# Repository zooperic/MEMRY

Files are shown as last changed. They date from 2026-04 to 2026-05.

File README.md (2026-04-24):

# MEMRY — Roadmap

## Milestone 0 — Decisions & Research ✅
*Completed April 2025*
- Product concept locked (WiFi Live, Polaroid form factor)
- Hardware stack decided (XIAO ESP32C3 + Waveshare 4.2" + 300mAh LiPo)
- India BOM researched with prices in INR
- Architecture designed
- NFC/Snap scoped out for POC (iOS complexity + deadline)

---

## Milestone 1 — Hardware Design ✅
*Completed April 2025*
- [x] Finalise shell dimensions (95×115×11mm)
- [x] Two-piece design: front body + plain back panel (no text, no emboss)
- [x] USB-C notch on right edge
- [x] M2 screw bosses (4 corners, BIN=6mm inset) — secure on impact
- [x] Rim ledge (RIM_W=2.5mm, RIM_H=1.5mm) with gasket groove
- [x] Magnet pockets: blind design spanning both pieces
      — Back panel: 20mm through-hole (1.5mm deep)
      — Front body rim face: 20mm blind recess (2.0mm deep)
      — Combined: 3.5mm total pocket, magnet 3.0mm, 0.5mm PLA floor
      — Ghost rings (raised 0.4mm) mark position on fridge face
- [x] STL files exported and validated (single body, watertight, correct dims)
      — memry_front_body_v4.stl (95×115×11mm)
      — memry_back_panel_v4.stl (87×107×1.9mm, fits inside rim)
- [ ] Submit STLs to local Pune 3D print service (print 4× each)

---

## Milestone 2 — Order Everything
*Target: April 22, 2025 (order) → May 1 (receive)*

### Electronics (Robu.in)
- [ ] 4× Waveshare 4.2" B&W e-ink display (400×300px, SPI)
- [ ] 4× Seeed XIAO ESP32C3
- [ ] 4× 3.7V 300mAh slim LiPo (JST-PH 2.0mm, ~2.5mm thick)
- [ ] Dupont jumper wires F-F 10cm (pack of 40)
- [ ] 1× breadboard (for firmware POC before assembly)

### Hardware (Amazon.in)
- [ ] N52 neodymium disc magnets 20mm×3mm — pack of 20
- [ ] M2×6mm self-tapping screws — pack of 20
- [ ] PCB conformal coating spray (~₹300)

### Consumables (local hardware store)
- [ ] Clear silicone sealant — Fevikwik Silicone or equivalent (~₹80)
- [ ] 2-part epoxy — for locking magnets (~₹60)

### 3D Print (local Pune service)
- [ ] memry_front_body_v4.stl — print 4× (white PLA, 0.15mm, face-down)
- [ ] memry_back_panel_v4.stl — print 4× (white PLA, 0.15mm, outside-face-down)

---

## Milestone 3 — Firmware POC
*Target: when hardware arrives (~May 1)*
*Status: PARKED — display ordered (Waveshare 3.6" Spectra 6), waiting on delivery*

### What's done (pre-hardware)
- [x] Full firmware scaffold: WiFi connect, ETag fetch, deep sleep cycle
- [x] WiFi provisioning portal (captive portal hotspot, no hardcoded creds)
- [x] Battery ADC monitoring spec'd, `bmp_render.h` written (needs color swap)
- [x] Mock server written (Node.js, zero deps)

### Do on hardware arrival
- [ ] Confirm driver chip from PCB sticker → write `color_render.h` (4bpp 6-color)
- [ ] Update display init in `memry.ino` to Spectra 6 driver
- [ ] Wire + breadboard test, run Waveshare stock demo first
- [ ] Flash MEMRY firmware, confirm color image renders
- [ ] End-to-end: upload color photo → appears on display
- [ ] Measure actual current draw in each state

### Shell update (Tinkercad, ~10 min)
- [ ] Resize window: 85x85mm → 85x58mm (Spectra 6 active area 84.6x56.4mm)
- [ ] Bottom strip grows 23mm → ~31mm (more Polaroid-authentic)
- [ ] Re-export STLs, resubmit to Pune printer

---

## Milestone 4 — Web App
*Target: April–May 2025 (building now)*
*Status: IN PROGRESS — starting while hardware ships*

### Stack
- Next.js 14 (App Router) · TypeScript · Tailwind · shadcn/ui
- Supabase (Auth + Postgres + Storage)
- Sharp.js image pipeline (server-side) · Vercel hosting

### Core features
- [ ] Supabase project setup (auth, DB schema, storage bucket)
- [ ] Next.js scaffold with Supabase auth (email/password)
- [ ] Upload flow: drag/drop → 6-color quantise → store BMP
- [ ] Device API: GET /api/device/{id}/current-image (ETag + X-Sleep-Hours + X-Battery-Mv)
- [ ] Dashboard: device cards, current photo, battery level badge, last-seen
- [ ] Storage usage: total bucket size + per-device breakdown
- [ ] Photo manager: set active, delete per-photo, clear all for device
- [ ] Device pairing: enter ID → name it → done
- [ ] Contributor invite by email (owner vs contributor roles)
- [ ] Deploy to Vercel

### Image pipeline (Spectra 6 color)
- [ ] Sharp.js resize to 600x400 (cover, centred)
- [ ] Quantise to 6-color palette: Black/White/Green/Blue/Red/Yellow
- [ ] Pack as 4bpp (2 pixels per byte) for device
- [ ] Store JPEG preview separately for dashboard thumbnails

### Polish
- [ ] Mobile-first (primary users on phone)
- [ ] Polaroid upload preview (simulated 6-color render before sending)
- [ ] Error states: device offline, image too large, upload failure
- [ ] Warm cream/ink aesthetic matching WIKI.html design language

---

## Milestone 5 — Integration + Assembly
*Target: June 2–15, 2025*
- [ ] Point all 4 firmware units at live server
- [ ] End-to-end test: web upload → fridge refresh
- [ ] Test rotation / auto-cycle
- [ ] Test with real photos (dithering quality check)
- [ ] Assemble all 4 shells (follow splash-protection sequence below)
- [ ] Charge all units via USB-C
- [ ] Confirm all 4 units connect to WiFi and poll correctly

### Assembly sequence (per unit)
1. Breadboard test first — confirm display + XIAO + LiPo work
2. Conformal coat — spray XIAO + all solder joints, cure 24h
3. Seat display — place face-down in display bay, route FPC ribbon
4. Seal display edge — thin silicone bead around window perimeter (inside)
5. Seat XIAO + LiPo — component bay, connect FPC jumpers + JST battery
6. Fill gasket groove — clear silicone sealant into rim groove
7. Drop back panel — self-locates inside rim ledge, press evenly
8. Drive 4× M2×6mm screws — corners, firm but don't overtighten
9. Insert magnets — drop N52 into ghost-ring holes from outside
10. Epoxy magnets — fill with 2-part epoxy, cure 30min

---

## Milestone 6 — Polish
*Target: June 16 – July 6, 2025*
- [ ] UI polish — mobile-first web app
- [ ] Polaroid preview on upload (simulated e-ink look)
- [ ] Error handling (device offline, WiFi failure, image too large)
- [ ] Domain: memry.app (or similar)
- [ ] Write setup guide for Jo (one-page PDF gift insert)
- [ ] Label each unit with small ID sticker inside back panel during assembly

---

## Milestone 7 — Gift Ready 🎁
*Target: July 11, 2025 (one week before July 18)*
- [ ] All 4 units assembled, charged, tested
- [ ] Server live and stable
- [ ] Jo's account created, devices paired
- [ ] Friends invited as contributors
- [ ] First photo pre-loaded on each device
- [ ] Gift packaged

---

## v2 Scope (Post-Birthday)

### Near term (Aug–Oct 2025)
- NFC Snap variant — revisit with proper iOS CoreNFC testing
- Flutter app — single interface for both Snap + Live
- Push updates (WebSocket) — instant refresh when photo is published
- Image filters on upload (grayscale styles, contrast, vintage)
- Caption rendering on bottom Polaroid strip

### Medium term (2026)
- Custom PCB — replace XIAO devkit, reduce to 8mm shell
- Injection moulded ABS shell — scale economics
- Direct display factory sourcing (50+ unit MOQ)
- Public launch — anyone can create an account and buy a MEMRY
- Subscription model — free tier (1 device, 5 photos) + paid (unlimited)

### Long term / ideas
- Physical MEMRY store — gift-ready packaged units
- Multi-frame — 2×2 grid of MEMRY units that show one big photo
- Color display — when 6-color NFC panels become more power efficient
- MEMRY for businesses — office walls, conference rooms

---

*Roadmap v1.2 · April 2025 · 87 days to July 11*

---

## LLM / AI Software Roadmap

### v2 — Natural Language Interface
- [ ] LLM command bar: "Show something cheerful on Jo's fridge" → picks + publishes
- [ ] Google Photos OAuth integration
- [ ] Natural language scheduling: "Show beach photos this week"

### v2 — Smart Curation
- [ ] Vision model scores photos for warmth, faces, composition
- [ ] Auto-suggest best photo for fridge
- [ ] Smart album: LLM picks best from a set based on vibe

### v3 — Automation
- [ ] "Every Monday morning, pick a random memory from the past year"
- [ ] Event awareness: birthdays, anniversaries → auto-queue relevant photos
- [ ] Multi-device: "Update all MEMRYs with something warm for the holidays"

---

## Smart Home / Matter Integration (v3+)

### Why Matter
Matter is the open smart home standard backed by Google, Apple, Amazon and Samsung.
ESP32C3 — the exact chip used in MEMRY — is one of Matter's reference MCUs and has
an official Matter SDK. No hardware changes needed.

### What it unlocks
- MEMRY appears in Google Home / Apple Home / Alexa as a native device
- Voice: "Hey Google, cycle the kitchen frame"
- Routines: "Every morning at 8am, show a new photo"
- Local network control — no cloud middleman

### Standards evaluated
| Standard | Verdict |
|---|---|
| **Matter over WiFi** | ✅ Best long-term bet — one standard, all ecosystems, ESP32C3 native |
| **Home Assistant (MQTT/ESPHome)** | ✅ Good for dev/power users, requires self-hosted HA |
| **Google Assistant SDK direct** | ⚠ Deprecated in favour of Matter |
| **Apple HomeKit (esp-homekit-sdk)** | ⚠ Works on ESP32 but MFi cert is a headache for DIY |

### Why it's v3 scope
Matter adds significant firmware complexity — commissioning flow, Thread/WiFi
selection, device descriptors. The POC deadline (July 2025) doesn't allow for it.
The hardware foundation is already correct — it's purely a firmware + web app change.

### Milestone placeholder
- [ ] v3 — Matter commissioning on XIAO ESP32C3
- [ ] v3 — Google Home device type: "Display" or custom "Photo Frame"
- [ ] v3 — Routine support: voice-triggered photo cycle
- [ ] v3 — Home Assistant ESPHome alternative for maker/dev users

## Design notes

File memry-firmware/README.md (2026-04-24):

# MEMRY Firmware — Spectra 6 Color

Hardware confirmed: Waveshare 3.6" e-Paper HAT+ (E), SKU 32650, Spectra 6, 600×400.

---

## File structure

```
firmware_color/
├── memry/
│   ├── memry.ino           ← main sketch (open this in Arduino IDE)
│   ├── config.h            ← per-device settings, edit before flashing
│   ├── epd3in6e_driver.h   ← Spectra 6 SPI driver (no GxEPD2 needed)
│   └── wifi_provision.h    ← captive portal WiFi setup
└── mock-server.js          ← local test server (Node.js, no deps)
```

---

## Arduino IDE setup

### 1. Board package
Preferences → Additional boards URLs:
```
https://files.seeedstudio.com/arduino/package_seeeduino_boards_index.json
```
Install: **Seeed Studio XIAO Series** from Boards Manager.

### 2. Select board
`Tools → Board → Seeed XIAO ESP32C3`

### 3. Libraries (Library Manager)
- `ArduinoJson` by Benoit Blanchon (v6.x)
- No GxEPD2 needed — driver is included in `epd3in6e_driver.h`

---

## Wiring (breadboard test)

Use the **9-pin breakout connector** on the right side of the HAT+ PCB.
Do NOT use the 40-pin Pi header.

```
HAT+ breakout    XIAO ESP32C3
─────────────────────────────────────
GND           →  GND
VCC           →  3.3V
DIN (MOSI)    →  D10  (GPIO3)
CLK (SCK)     →  D8   (GPIO2)
CS            →  D7   (GPIO20)
DC            →  D3   (GPIO21)
RST           →  D0   (GPIO9)
BUSY          ←  D1   (GPIO10)
PWR           →  3.3V  ⚠️ REQUIRED — ties to same 3.3V rail
```

⚠️  **PWR pin is critical.** Without 3.3V on PWR the display will not power on.
    Tie it to the same 3.3V rail as VCC on your breadboard.

⚠️  **Interface switch** on HAT+ PCB must be at position **0** (4-line SPI).
    It ships at 0 — leave it alone.

---

## First flash (step by step)

### 1. Edit config.h
```cpp
#define DEVICE_ID  "memry-001"         // unique per unit
#define SERVER_URL "http://192.168.x.x:3001"  // your laptop LAN IP
```

### 2. Start mock server
```bash
node mock-server.js
```
Prints your LAN IP — paste that into `SERVER_URL`.

### 3. Wire display per table above

### 4. Flash
Open `memry/memry.ino` → Upload.

### 5. Serial Monitor (115200 baud)
You should see:
```
── MEMRY wake #1  device=memry-001 ──
EPD init done
WiFi: connecting to 'YourNetwork' (attempt 1)
WiFi connected: 192.168.1.xx
Battery: 3920mV
Fetching http://192.168.1.42:3001/api/device/memry-001/current-image
HTTP 200
Content-Length: 120000
EPD rendering rotated 120000 bytes (400×600)...
EPD refreshing rotated (this takes ~19s)...
EPD rotated render done in 22438ms
Sleeping 4h...
```

Display will show the 6-color test pattern after ~22 seconds of refreshing.

---

## Orientation

The display's native pixel layout is **landscape** (600 wide × 400 tall).
The shell mounts it **portrait** (400 wide × 600 tall).

The firmware calls `epdRenderRotated()` which rotates the image 90° clockwise
in RAM before sending. This is the default.

If you want landscape orientation, change `memry.ino`:
```cpp
// Change this:
epdRenderRotated(imgBuf, imgLen);
// To this:
epdRender(imgBuf, imgLen);
```

And update the server to produce images at 600×400 (landscape) instead of
rotating them to 400×600 portrait.

---

## Image format

The server sends raw 4bpp packed binary:
- 2 pixels per byte
- High nibble = left pixel, low nibble = right pixel
- Color indices: Black=0, White=1, Green=2, Blue=3, Red=4, Yellow=5
- Total size: 600 × 400 / 2 = **120,000 bytes** exactly

The mock server generates a 6-color test pattern automatically on first run.

To serve your own image:
```bash
# Convert any photo using ImageMagick + custom palette
# (The web app will do this automatically — for manual testing:)
convert your-photo.jpg \
  -resize 600x400^ -gravity center -extent 600x400 \
  -dither FloydSteinberg \
  -remap spectra6-palette.png \
  your-photo-quantised.png
# Then convert to raw 4bpp using the included convert.js script
```

---

## Mock server quick reference

```bash
# Regenerate test pattern
curl http://localhost:3001/test-pattern

# Force device to re-render on next wake
curl http://localhost:3001/reset-etag

# See server state + recent device requests
curl http://localhost:3001/status
```

---

## Per-unit checklist

| Unit | DEVICE_ID | WiFi via portal | Flashed | Display tested |
|---|---|---|---|---|
| 1 | memry-001 | [ ] | [ ] | [ ] |
| 2 | memry-002 | [ ] | [ ] | [ ] |
| 3 | memry-003 | [ ] | [ ] | [ ] |
| 4 | memry-004 | [ ] | [ ] | [ ] |

---

## Troubleshooting

| Symptom | Cause | Fix |
|---|---|-----|
| Display stays white/blank | PWR pin not connected | Wire PWR → 3.3V |
| BUSY timeout in Serial | Wrong wiring | Re-check all 8 pins |
| Image garbled/wrong colors | Wrong resolution sent | Confirm 120,000 bytes |
| WiFi never connects | First boot | Connect to "MEMRY-Setup" hotspot |
| Crash / malloc failed | 120KB not available | Unlikely on XIAO C3 (400KB) — check other allocations |
| Refresh takes >60s | BUSY stuck HIGH | Check BUSY wiring and RST pulse |

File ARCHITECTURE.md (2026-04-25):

# MEMRY — Architecture

## System Overview

```
[Person] ──upload──▶ [Web App] ──store──▶ [Supabase]
                         │                    │
                   [Image Pipeline]            │
                   Sharp.js                    │
                   → color quantise (Spectra 6)│
                   → Floyd-Steinberg (B&W)     │
                   → BMP output                │
                         │                    │
                   [Storage bucket] ◀──────────┘
                         │
              GET /api/device/{id}/current-image
                         │
                  [MEMRY Device]
          XIAO ESP32C3 wakes from deep sleep
          → WiFi connect → poll server
          → receive BMP → render to e-ink
          → hibernate display → deep sleep
```

---

## Hardware Layer

### Device Stack (per unit)
```
Front wall (1.0mm PLA)
Display glass (1.2mm) + PCB driver (1.5mm)
FPC ribbon gap (0.5mm)
XIAO ESP32C3 (3.5mm) beside LiPo (2.5mm)
Rim ledge + back panel (1.5mm PLA)
─────────────────────────────────────────
~11mm total
```

### Shell (v4 — two-piece)
- **Front body:** 95×115×11mm · display window · component bay · rim ledge · gasket groove · M2 boss pillars
- **Back panel:** 87×107×1.9mm · ghost rings · magnet through-holes · M2 countersunk holes
- **Closure:** 4× M2×6mm self-tapping screws through panel → into boss pillars
- **Magnets:** N52 20mm×3mm disc · blind pocket split across both pieces · epoxied post-assembly
- **Splash resistance:** silicone sealant in gasket groove + conformal coat on electronics

### Display Decision
- **Confirmed:** Waveshare 3.6" E-Paper HAT+ (E) — SKU 32650
  - Panel: Spectra 6 (E6) — 6-pigment ACeP technology
  - Resolution: 600×400px (landscape) → 400×600px (portrait mounted in shell)
  - Active area: 84.6×56.4mm
  - Driver chip: UC8253 (confirmed from PCB + datasheet)
  - Interface: 4-line SPI (switch set to position 0)
  - Refresh time: ~19 seconds full update
  - Color encoding: 4bpp packed, 2px/byte (6 colors: B/W/G/B/R/Y)
  - Power requirements: PWR pin MUST tie to 3.3V (critical!)
  - Portrait mounting: setRotation(1) in firmware for landscape shell
  - Portrait mounted in landscape shell via setRotation(1)
- **Dropped:** Waveshare 4.2" B&W (original plan — superseded by color)

### Power Budget
```
State               Current      Duration      Energy/day
─────────────────────────────────────────────────────────
Deep sleep          44µA         ~23h 59m      ~1.06 mWh
WiFi connect        ~80mA avg    ~8 seconds    ~0.18 mWh
Image fetch         ~60mA        ~3 seconds    ~0.05 mWh
E-ink refresh       ~26mA        ~4 seconds    ~0.03 mWh
E-ink sleep         ~0µA         always after  0 mWh
─────────────────────────────────────────────────────────
Total/day                                      ~1.32 mWh

Battery: 300mAh × 3.7V × 0.85 = 944 mWh usable
Life: 944 / 1.32 ≈ 715 days theoretical → realistic 3–5 months
```

### Wiring
```
Waveshare e-ink     →   XIAO ESP32C3
────────────────────────────────────
VCC              →   3.3V
GND              →   GND
DIN (MOSI)       →   D10 (GPIO3)
CLK (SCK)        →   D8  (GPIO2)
CS               →   D7  (GPIO20)
DC               →   D3  (GPIO21)
RST              →   D0  (GPIO9)
BUSY             ←   D1  (GPIO10)

LiPo 300mAh      →   XIAO BAT+ / BAT-  (JST-PH 2.0mm)
USB-C            →   XIAO USB-C (charge + flash)
```

---

## Firmware Layer

### Lifecycle
```
Boot / wake from deep sleep
  │
  ├─ Connect WiFi (stored creds) — timeout 20s, retry 3×
  ├─ GET /api/device/{DEVICE_ID}/current-image
  │    → check ETag (stored in RTC memory)
  │    → if unchanged: skip render, sleep immediately
├─ Render BMP to e-ink (custom epd3in6e_driver.h) — ~19s full refresh
  ├─ Display hibernate (0µA)
  └─ Deep sleep SLEEP_INTERVAL (default 4h, from X-Sleep-Hours header)
```

### Key Config
```cpp
const char* WIFI_SSID  = "Jo_WiFi";
const char* WIFI_PASS  = "password";
const char* DEVICE_ID  = "memry-001";
const char* SERVER     = "https://api.memry.app";
uint64_t    SLEEP_US   = 4ULL * 3600 * 1000000;
```

### Libraries
```
GxEPD2       (NOT USED NOW) E-ink driver (supports Waveshare 4" Spectra 6 + 4.2" B&W) 
HTTPClient    HTTP requests
ArduinoJson   Parse response headers
Preferences   Store WiFi creds + device ID in flash
WiFi          Network connectivity (ESP32 built-in)
WebServer     Provisioning portal (ESP32 built-in)
DNSServer     Captive portal for WiFi setup (ESP32 built-in)

Custom drivers (no external deps):
epd3in6e_driver.h    SPI driver for Waveshare 3.6" Spectra 6
wifi_provision.h     Captive portal WiFi provisioning
bmp_render.h         Direct framebuffer rendering (no font libs)
```

---

## Software Layer

### Web App Stack
```
Next.js 14 (App Router)
  ├── /app
  │     ├── page.tsx              ← Dashboard
  │     ├── /device/[id]          ← Photo manager
  │     └── /upload               ← Upload + preview
  ├── /api
  │     ├── /device/[id]/image    ← Device-facing: serve BMP
  │     ├── /devices              ← CRUD
  │     └── /photos               ← Upload, publish, delete
  └── /lib
        ├── supabase.ts
        ├── imageProcess.ts       ← Sharp.js pipeline
        └── dither.ts             ← Color quantise + Floyd-Steinberg

Supabase: Auth · Postgres · Storage (private buckets)
Hosting: Vercel (free tier)
```

### Image Processing Pipeline
```
Upload (JPEG/PNG/HEIC)
  │
  ├─ Resize to 600×400 (cover, centre crop) — Sharp.js
  │
  ├─ Quantise to 6-color Spectra 6 palette
  │    Black=0x0 · White=0x1 · Green=0x2 · Blue=0x3 · Red=0x4 · Yellow=0x5
  │    Each pixel = 4 bits · 2 pixels packed per byte
  │
  ├─ Output: raw 4bpp packed buffer (~120KB) → device format
  │   + JPEG preview at 600×400 for dashboard thumbnails
  │
  └─ Store in Supabase Storage
       /processed/{device_id}/{photo_id}.bin   ← device image
       /previews/{device_id}/{photo_id}.jpg    ← dashboard thumbnail
```

### Database Schema
```sql
CREATE TABLE devices (
  id            TEXT PRIMARY KEY,        -- 'memry-001'
  name          TEXT,                    -- 'Jo's Kitchen'
  owner_id      UUID REFERENCES auth.users,
  sleep_hours   INT DEFAULT 4,
  display_type  TEXT DEFAULT 'color',    -- 'color' | 'bw'
  created_at    TIMESTAMPTZ DEFAULT NOW()
);

CREATE TABLE photos (
  id              UUID PRIMARY KEY DEFAULT gen_random_uuid(),
  device_id       TEXT REFERENCES devices(id) ON DELETE CASCADE,
  uploaded_by     UUID REFERENCES auth.users,
  storage_path    TEXT,
  processed_path  TEXT,
  caption         TEXT,
  is_active       BOOLEAN DEFAULT FALSE,
  created_at      TIMESTAMPTZ DEFAULT NOW()
);

CREATE TABLE device_settings (
  device_id       TEXT PRIMARY KEY REFERENCES devices(id),
  rotation_mode   TEXT DEFAULT 'manual',
  rotation_hours  INT DEFAULT 24
);

CREATE TABLE contributors (
  device_id       TEXT REFERENCES devices(id) ON DELETE CASCADE,
  user_id         UUID REFERENCES auth.users,
  invited_by      UUID REFERENCES auth.users,
  PRIMARY KEY (device_id, user_id)
);
```

### Device API
```
GET /api/device/{id}/current-image

Response:
  Content-Type:  image/bmp
  ETag:          {photo_id}
  X-Sleep-Hours: 4
  Cache-Control: no-store

Body: raw BMP bytes

Auth:      none — device ID is the key
Rate:      1 req / 30 min / device ID
```

### Account Model
```
Owner (gifter):
  - Pairs devices, manages all photos, invites contributors

Contributor (Jo, friends):
  - Uploads + publishes photos to invited devices
  - Cannot unpair, delete, or change settings
```

---

## Security
- Device API unauthenticated but rate-limited + device-ID-gated
- Web app: Supabase RLS — users only see own devices/photos
- Storage: private buckets, signed URLs only
- Device ID: 8-char random string flashed at firmware build time

---

## Smart Home (v3 — no hardware change needed)
- **Matter over WiFi** — ESP32C3 is a reference chip, official SDK exists
- **Home Assistant / ESPHome** — good stepping stone for dev/power users
- Enables: Google Home native device, voice control, routines

---

*Architecture v1.2 · April 2025*

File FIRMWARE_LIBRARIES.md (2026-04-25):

# MEMRY Firmware — Library Dependencies

## Required Libraries (Arduino Library Manager)

### ArduinoJson v6.x
**Author:** Benoit Blanchon  
**Purpose:** Parse JSON responses from server  
**Install:** Arduino IDE → Library Manager → search "ArduinoJson"  
**Usage in firmware:**
```cpp
#include <ArduinoJson.h>
DynamicJsonDocument doc(1024);
deserializeJson(doc, response);
int sleepHours = doc["sleep_hours"];
```

### ESP32 Built-in Libraries
These ship with the Seeed XIAO ESP32C3 board package — no separate install needed.

**WiFi.h** — Network connectivity  
**HTTPClient.h** — HTTP requests to server  
**Preferences.h** — Flash storage (WiFi creds, device ID, ETag)  
**WebServer.h** — Provisioning portal HTTP server  
**DNSServer.h** — Captive portal for WiFi setup  

## Custom Drivers (No External Dependencies)

### epd3in6e_driver.h
**Purpose:** SPI driver for Waveshare 3.6" Spectra 6 display  
**Location:** `/memry-firmware/epd3in6e_driver.h`  
**Why custom:** GxEPD2 doesn't support Spectra 6 4bpp color encoding  
**Key functions:**
- `EPD_3IN6E_Init()` — Initialize display SPI + power sequence  
- `EPD_3IN6E_Display(uint8_t *image)` — Stream 120KB 4bpp buffer to display  
- `EPD_3IN6E_Sleep()` — Enter 0µA hibernation mode  

### wifi_provision.h
**Purpose:** Captive portal for WiFi credential entry  
**Location:** `/memry-firmware/wifi_provision.h`  
**How it works:**
1. Boot with no stored WiFi → creates AP "MEMRY-SETUP"
2. User connects → captive portal redirects to 192.168.4.1
3. HTML form for SSID/password entry
4. Credentials saved to Preferences flash storage
5. Reboot → normal WiFi connect mode

### bmp_render.h
**Purpose:** Direct framebuffer rendering (status screens, QR codes)  
**Location:** `/memry-firmware/bmp_render.h`  
**Why custom:** No font libraries needed — we draw pixels directly  
**Usage:** Provisioning portal QR code + "Scanning..." status text

## Board Package

**Seeed XIAO ESP32C3 Board Package**  
**Install:** Arduino IDE → Preferences → Additional Board Manager URLs: https://files.seeedstudio.com/arduino/package_seeedstudio_boards_index.json

Then: Tools → Board → Boards Manager → search "Seeed ESP32"

## Verification

To confirm all dependencies are met:
```cpp
// At top of memry.ino:
#include <WiFi.h>          // ✅ ESP32 core
#include <HTTPClient.h>     // ✅ ESP32 core
#include <Preferences.h>    // ✅ ESP32 core
#include <ArduinoJson.h>    // ❌ Install from Library Manager
#include "epd3in6e_driver.h" // ✅ Custom (in repo)
#include "wifi_provision.h"  // ✅ Custom (in repo)
```

If build fails on `#include <ArduinoJson.h>`, install from Library Manager.

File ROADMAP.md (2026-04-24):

# MEMRY — Roadmap

## Milestone 0 — Decisions & Research ✅
*Completed April 2025*
- Product concept locked (WiFi Live, Polaroid form factor)
- Hardware stack decided (XIAO ESP32C3 + Waveshare 4.2" + 300mAh LiPo)
- India BOM researched with prices in INR
- Architecture designed
- NFC/Snap scoped out for POC (iOS complexity + deadline)

---

## Milestone 1 — Hardware Design ✅
*Completed April 2025*
- [x] Finalise shell dimensions (95×115×11mm)
- [x] Two-piece design: front body + plain back panel (no text, no emboss)
- [x] USB-C notch on right edge
- [x] M2 screw bosses (4 corners, BIN=6mm inset) — secure on impact
- [x] Rim ledge (RIM_W=2.5mm, RIM_H=1.5mm) with gasket groove
- [x] Magnet pockets: blind design spanning both pieces
      — Back panel: 20mm through-hole (1.5mm deep)
      — Front body rim face: 20mm blind recess (2.0mm deep)
      — Combined: 3.5mm total pocket, magnet 3.0mm, 0.5mm PLA floor
      — Ghost rings (raised 0.4mm) mark position on fridge face
- [x] STL files exported and validated (single body, watertight, correct dims)
      — memry_front_body_v4.stl (95×115×11mm)
      — memry_back_panel_v4.stl (87×107×1.9mm, fits inside rim)
- [ ] Submit STLs to local Pune 3D print service (print 4× each)

---

## Milestone 2 — Order Everything
*Target: April 22, 2025 (order) → May 1 (receive)*

### Electronics (Robu.in)
- [ ] 4× Waveshare 4.2" B&W e-ink display (400×300px, SPI)
- [ ] 4× Seeed XIAO ESP32C3
- [ ] 4× 3.7V 300mAh slim LiPo (JST-PH 2.0mm, ~2.5mm thick)
- [ ] Dupont jumper wires F-F 10cm (pack of 40)
- [ ] 1× breadboard (for firmware POC before assembly)

### Hardware (Amazon.in)
- [ ] N52 neodymium disc magnets 20mm×3mm — pack of 20
- [ ] M2×6mm self-tapping screws — pack of 20
- [ ] PCB conformal coating spray (~₹300)

### Consumables (local hardware store)
- [ ] Clear silicone sealant — Fevikwik Silicone or equivalent (~₹80)
- [ ] 2-part epoxy — for locking magnets (~₹60)

### 3D Print (local Pune service)
- [ ] memry_front_body_v4.stl — print 4× (white PLA, 0.15mm, face-down)
- [ ] memry_back_panel_v4.stl — print 4× (white PLA, 0.15mm, outside-face-down)

---

## Milestone 3 — Firmware POC
*Target: hardware arrived April 2025*
*Status: READY TO TEST — all firmware written, hardware confirmed, breadboard next*

### Hardware confirmed
- [x] Waveshare 3.6" e-Paper HAT+ (E), SKU 32650, Spectra 6, 600×400
- [x] Seeed Studio XIAO-ESP32-C3 confirmed genuine
- [x] Interface switch confirmed at 0 (4-line SPI) ✓
- [x] PWR pin identified — must tie to 3.3V (critical, easy to miss)

### Firmware written and ready
- [x] Full firmware scaffold: WiFi connect, ETag fetch, deep sleep cycle
- [x] WiFi provisioning portal (captive portal, no hardcoded creds)
- [x] `epd3in6e_driver.h` — complete Spectra 6 SPI driver (no GxEPD2 needed)
- [x] `epdRender()` — landscape direct stream
- [x] `epdRenderRotated()` — 90° CW rotation in RAM for portrait shell mount
- [x] Battery ADC (A0/GPIO0, voltage divider, X-Battery-Mv header)
- [x] Mock server updated for 120,000-byte 4bpp color format + 6-color test pattern
- [x] Status + provisioning screens drawn via raw framebuffer (no font library needed)

### Still to do (breadboard session)
- [ ] Wire display + XIAO per README wiring table (8 wires + PWR)
- [ ] Flash firmware, run mock server, confirm display renders test pattern
- [ ] Confirm ~19s refresh time acceptable
- [ ] End-to-end: web app upload → device renders
- [ ] Measure actual current draw (deep sleep, WiFi active, refresh)

### Shell update (Tinkercad, ~10 min)
- [ ] Resize window: 85x85mm → 85x58mm (Spectra 6 active area 84.6x56.4mm)
- [ ] Bottom strip grows 23mm → ~31mm (more Polaroid-authentic)
- [ ] Re-export STLs, resubmit to Pune printer

---

## Milestone 4 — Web App
*Target: April–May 2025 (building now)*
*Status: IN PROGRESS — starting while hardware ships*

### Stack
- Next.js 14 (App Router) · TypeScript · Tailwind · shadcn/ui
- Supabase (Auth + Postgres + Storage)
- Sharp.js image pipeline (server-side) · Vercel hosting

### Core features
- [ ] Supabase project setup (auth, DB schema, storage bucket)
- [ ] Next.js scaffold with Supabase auth (email/password)
- [ ] Upload flow: drag/drop → 6-color quantise → store .bin (120KB) + .jpg preview
- [ ] Device API: GET /api/device/{id}/current-image (ETag + X-Sleep-Hours + X-Battery-Mv)
- [ ] Dashboard: device cards, current photo, battery level badge, last-seen
- [ ] Storage usage: total bucket size + per-device breakdown
- [ ] Photo manager: set active, delete per-photo, clear all for device
- [ ] Device pairing: enter ID → name it → done
- [ ] Contributor invite by email (owner vs contributor roles)
- [ ] Deploy to Vercel

### Image pipeline (Spectra 6 color) — confirmed format
- [ ] Sharp.js resize to 600×400 (cover, centred) — landscape native orientation
- [ ] Quantise to 6-color palette: Black=0, White=1, Green=2, Blue=3, Red=4, Yellow=5
- [ ] Pack as 4bpp (2 pixels per byte, high nibble = left pixel)
- [ ] Output: raw binary `.bin` file — exactly 120,000 bytes (600×400÷2)
- [ ] Store JPEG preview at 600×400 separately for dashboard thumbnails
- [ ] Device API serves `.bin` as `application/octet-stream` (not image/bmp)
- [ ] ETag computed from binary content hash

### Polish
- [ ] Mobile-first (primary users on phone)
- [ ] Polaroid upload preview (simulated 6-color render before sending)
- [ ] Error states: device offline, image too large, upload failure
- [ ] Warm cream/ink aesthetic matching WIKI.html design language

---

## Milestone 5 — Integration + Assembly
*Target: June 2–15, 2025*
- [ ] Point all 4 firmware units at live server
- [ ] End-to-end test: web upload → fridge refresh
- [ ] Test rotation / auto-cycle
- [ ] Test with real photos (dithering quality check)
- [ ] Assemble all 4 shells (follow splash-protection sequence below)
- [ ] Charge all units via USB-C
- [ ] Confirm all 4 units connect to WiFi and poll correctly

### Assembly sequence (per unit)
1. Breadboard test first — confirm display + XIAO + LiPo work
2. Conformal coat — spray XIAO + all solder joints, cure 24h
3. Seat display — place face-down in display bay, route FPC ribbon
4. Seal display edge — thin silicone bead around window perimeter (inside)
5. Seat XIAO + LiPo — component bay, connect FPC jumpers + JST battery
6. Fill gasket groove — clear silicone sealant into rim groove
7. Drop back panel — self-locates inside rim ledge, press evenly
8. Drive 4× M2×6mm screws — corners, firm but don't overtighten
9. Insert magnets — drop N52 into ghost-ring holes from outside
10. Epoxy magnets — fill with 2-part epoxy, cure 30min

---

## Milestone 6 — Polish
*Target: June 16 – July 6, 2025*
- [ ] UI polish — mobile-first web app
- [ ] Polaroid preview on upload (simulated e-ink look)
- [ ] Error handling (device offline, WiFi failure, image too large)
- [ ] Domain: memry.app (or similar)
- [ ] Write setup guide for Jo (one-page PDF gift insert)
- [ ] Label each unit with small ID sticker inside back panel during assembly

---

## Milestone 7 — Gift Ready 🎁
*Target: July 11, 2025 (one week before July 18)*
- [ ] All 4 units assembled, charged, tested
- [ ] Server live and stable
- [ ] Jo's account created, devices paired
- [ ] Friends invited as contributors
- [ ] First photo pre-loaded on each device
- [ ] Gift packaged

---

## v2 Scope (Post-Birthday)

### Near term (Aug–Oct 2025)
- NFC Snap variant — revisit with proper iOS CoreNFC testing
- Flutter app — single interface for both Snap + Live
- Push updates (WebSocket) — instant refresh when photo is published
- Image filters on upload (grayscale styles, contrast, vintage)
- Caption rendering on bottom Polaroid strip

### Medium term (2026)
- Custom PCB — replace XIAO devkit, reduce to 8mm shell
- Injection moulded ABS shell — scale economics
- Direct display factory sourcing (50+ unit MOQ)
- Public launch — anyone can create an account and buy a MEMRY
- Subscription model — free tier (1 device, 5 photos) + paid (unlimited)

### Long term / ideas
- Physical MEMRY store — gift-ready packaged units
- Multi-frame — 2×2 grid of MEMRY units that show one big photo
- Color display — when 6-color NFC panels become more power efficient
- MEMRY for businesses — office walls, conference rooms

---

*Roadmap v1.2 · April 2025 · 87 days to July 11*

---

## LLM / AI Software Roadmap

### v2 — Natural Language Interface
- [ ] LLM command bar: "Show something cheerful on Jo's fridge" → picks + publishes
- [ ] Google Photos OAuth integration
- [ ] Natural language scheduling: "Show beach photos this week"

### v2 — Smart Curation
- [ ] Vision model scores photos for warmth, faces, composition
- [ ] Auto-suggest best photo for fridge
- [ ] Smart album: LLM picks best from a set based on vibe

### v3 — Automation
- [ ] "Every Monday morning, pick a random memory from the past year"
- [ ] Event awareness: birthdays, anniversaries → auto-queue relevant photos
- [ ] Multi-device: "Update all MEMRYs with something warm for the holidays"

---

## Smart Home / Matter Integration (v3+)

### Why Matter
Matter is the open smart home standard backed by Google, Apple, Amazon and Samsung.
ESP32C3 — the exact chip used in MEMRY — is one of Matter's reference MCUs and has
an official Matter SDK. No hardware changes needed.

### What it unlocks
- MEMRY appears in Google Home / Apple Home / Alexa as a native device
- Voice: "Hey Google, cycle the kitchen frame"
- Routines: "Every morning at 8am, show a new photo"
- Local network control — no cloud middleman

### Standards evaluated
| Standard | Verdict |
|---|---|
| **Matter over WiFi** | ✅ Best long-term bet — one standard, all ecosystems, ESP32C3 native |
| **Home Assistant (MQTT/ESPHome)** | ✅ Good for dev/power users, requires self-hosted HA |
| **Google Assistant SDK direct** | ⚠ Deprecated in favour of Matter |
| **Apple HomeKit (esp-homekit-sdk)** | ⚠ Works on ESP32 but MFi cert is a headache for DIY |

### Why it's v3 scope
Matter adds significant firmware complexity — commissioning flow, Thread/WiFi
selection, device descriptors. The POC deadline (July 2025) doesn't allow for it.
The hardware foundation is already correct — it's purely a firmware + web app change.

### Milestone placeholder
- [ ] v3 — Matter commissioning on XIAO ESP32C3
- [ ] v3 — Google Home device type: "Display" or custom "Photo Frame"
- [ ] v3 — Routine support: voice-triggered photo cycle
- [ ] v3 — Home Assistant ESPHome alternative for maker/dev users

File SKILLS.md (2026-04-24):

# MEMRY — Skills & Tech Stack Reference

> Full context on tools, libraries and patterns across every layer.
> Updated to reflect color display (Spectra 6) and v4 two-piece shell.

---

## Frontend (Web App)

### Stack
- **Status:** Building now (April 2025) while hardware ships
- **Framework:** Next.js 14 (App Router, React Server Components)
- **Language:** TypeScript
- **Styling:** Tailwind CSS
- **UI components:** shadcn/ui (radix-based)
- **State:** Zustand (client) · React Query (server/cache)
- **File upload:** react-dropzone
- **Image preview:** HTML5 Canvas API — simulate dithered e-ink look (color + B&W modes)
- **Auth:** Supabase Auth
- **Hosting:** Vercel

### Key patterns
- Mobile-first (primary users on phone)
- Upload flow: drag image → canvas preview (color palette simulation) → select device → send
- Polaroid metaphor throughout — photo cards styled as Polaroid frames
- No dark mode for POC

### Libraries
```
sharp          Image processing (server-side, Node.js)
image-q        Color quantisation for Spectra 6 6-pigment palette
@supabase/ssr  Supabase client for Next.js App Router
next/image     Optimised image rendering
```

---

## Backend (API + Database)

### Stack
- **Runtime:** Node.js via Next.js API Routes (serverless)
- **Database:** Supabase Postgres
- **Auth:** Supabase Auth + RLS
- **Storage:** Supabase Storage (private buckets)
- **Image processing:** Sharp.js (serverless function)
- **Hosting:** Vercel free tier

### Image processing (Sharp.js)
```javascript
// Spectra 6 — 6-color 4bpp pipeline
// Step 1: resize + extract raw pixels
const { data, info } = await sharp(inputBuffer)
  .resize(600, 400, { fit: 'cover', position: 'centre' })
  .raw()
  .toBuffer({ resolveWithObject: true });

// Step 2: quantise each pixel to nearest Spectra 6 color
// Palette: Black=0, White=1, Green=2, Blue=3, Red=4, Yellow=5
const PALETTE = [
  [0,0,0], [255,255,255], [0,255,0],
  [0,0,255], [255,0,0], [255,255,0]
];
function nearest(r,g,b) {
  let best=0, bestD=Infinity;
  PALETTE.forEach(([pr,pg,pb],i)=>{
    const d=(r-pr)**2+(g-pg)**2+(b-pb)**2;
    if(d<bestD){bestD=d;best=i;}
  });
  return best;
}

// Step 3: pack 2 pixels per byte (4bpp)
const pixels = 600 * 400;
const packed = Buffer.alloc(pixels / 2);
for (let i = 0; i < pixels; i += 2) {
  const hi = nearest(data[i*3], data[i*3+1], data[i*3+2]);
  const lo = nearest(data[(i+1)*3], data[(i+1)*3+1], data[(i+1)*3+2]);
  packed[i/2] = (hi << 4) | lo;
}
// packed is the device image format (~120KB for 600x400)

// Step 4: JPEG preview for dashboard
const preview = await sharp(inputBuffer)
  .resize(600, 400, { fit: 'cover', position: 'centre' })
  .jpeg({ quality: 80 })
  .toBuffer();
```

### Supabase RLS
```sql
CREATE POLICY "owner_only" ON devices
  FOR ALL USING (owner_id = auth.uid());

CREATE POLICY "contributor_read" ON photos
  FOR SELECT USING (
    device_id IN (
      SELECT device_id FROM contributors WHERE user_id = auth.uid()
    )
  );
```

---

## Firmware (ESP32)

### Stack
- **Board:** Seeed XIAO ESP32C3
- **IDE:** Arduino IDE 2.x or PlatformIO
- **Language:** C++ (Arduino)
- **Display driver:** GxEPD2 (supports both Spectra 6 and 4.2" B&W)
- **HTTP:** HTTPClient
- **WiFi:** WiFi.h

### GxEPD2 config — Spectra 6 (primary)
```cpp
// Waveshare 4" Spectra 6 — check GxEPD2 library for exact class name
// As of 2025: GxEPD2_it60 or similar — verify against library release notes
#include <GxEPD2_3C.h> // or GxEPD2_565c for color variants
```

### GxEPD2 config — B&W fallback
```cpp
#include <GxEPD2_BW.h>
GxEPD2_BW<GxEPD2_420_GDEY042T81, GxEPD2_420_GDEY042T81::HEIGHT> display(
  GxEPD2_420_GDEY042T81(/*CS=*/D7, /*DC=*/D3, /*RES=*/D0, /*BUSY=*/D1)
);
```

### Deep sleep
```cpp
display.hibernate();
WiFi.disconnect(true);
WiFi.mode(WIFI_OFF);
esp_sleep_enable_timer_wakeup(SLEEP_INTERVAL_US);
esp_deep_sleep_start();
```

### ETag caching
```cpp
RTC_DATA_ATTR char lastEtag[64] = "";
// If ETag unchanged → skip render → sleep immediately
```

---

## Mechanical (Shell v4)

### Two-piece design
```
FRONT BODY  95×115×11mm  — display window, bays, rim ledge, boss pillars
BACK PANEL  87×107×1.9mm — ghost rings, magnet holes, screw countersinks
```

### Key parameters
```
RIM_W=2.5mm  RIM_H=1.5mm  — ledge that panel sits in
GW=1.4mm     GD=1.0mm     — gasket groove on rim face
BOD=6.5mm    BOH=7.5mm    — M2 boss outer dia + height
BIN=6.0mm                 — boss inset from outer edge
MAG_D=20mm   MAG_T=3.0mm  — magnet size
MAG_IN=16.0mm             — magnet inset from outer edge
BODY_REC=2.0mm            — body recess depth (pocket floor = 0.5mm)
```

### Print settings
```
Material:     White PLA
Layer height: 0.15mm
Infill:       20%
Walls:        3 perimeters
Supports:     None
Orientation:  Front body face-down · Back panel outside-face-down
```

### STL files
- `memry_front_body_v4.stl` — print 4×
- `memry_back_panel_v4.stl` — print 4×
- `memry_shell_v4.scad`     — parametric source

---

## Electrical

### Power states
| State | Current | Notes |
|---|---|---|
| Deep sleep | 44µA | XIAO spec |
| E-ink hibernate | ~0µA | Bistable — holds image forever |
| WiFi active | 80–150mA peak | Short burst only |
| E-ink refresh (color) | ~40mA | ~20–30s full Spectra 6 refresh |
| E-ink refresh (B&W) | ~26mA | ~4s full refresh |
| Charging | up to 500mA | XIAO charges at 500mA max |

### Rules
- E-ink VCC must be 3.3V — do NOT connect to 5V
- Always hibernate display after refresh
- SPI clock ≤ 4MHz on jumper wires
- Min refresh interval: 180s (Waveshare spec)

---

## Design (Visual / Brand)

### Palette
```
Cream:   #FAFAF8   Paper:  #F2EFE8
Ink:     #1A1612   Gold:   #C8A96E
```

### Typography
- Display: Playfair Display
- UI/Technical: DM Mono

### Web UI principles
- Mobile-first
- Polaroid metaphor — cards look like Polaroid frames
- Warm tones, upload flow is the hero
- Color preview: show simulated Spectra 6 palette render before confirming send

---

*Skills v1.2 · April 2025*

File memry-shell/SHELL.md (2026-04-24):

# MEMRY — Hardware Design

## Shell Dimensions (3D Print Spec)

```
TOP VIEW (front face)
┌─────────────────────────────────┐
│ ← 95mm →                        │
│  ┌───────────────────────────┐  │ ↑
│  │                           │  │ 7mm
│  │   E-INK DISPLAY WINDOW    │  │ ↓
│  │      85mm × 85mm          │  │
│  │                           │  │ 85mm
│  │   400×300px active area   │  │ window
│  │   (e-ink sits behind)     │  │
│  │                           │  │
│  └───────────────────────────┘  │
│                                 │ ↑
│   001        ·memry·            │ 23mm
│                                 │ ↓ Polaroid white strip
└─────────────────────────────────┘
         ← 95mm →         total H: 115mm

SIDE VIEW
┌──────────────────────────────────────┐
│ 1.0mm │ display │ gap │ MCU+batt │ 1.5mm │
└──────────────────────────────────────┘
  front   1.2+1.5  0.5   3.5+2.5    back
  wall    display  FPC   (beside    wall+
                   gap   each       magnet
                         other)
                    ←── ~11mm total ──→

BACK VIEW
┌─────────────────────────────────┐
│  ○                           ○  │  ← N52 magnet pockets (×4)
│     MEMRY v1.0                  │     20mm dia × 3mm deep
│     for Jo                      │     10mm from each corner
│                                 │
│                      [USB-C ▯]  │  ← 9×3.5mm notch, bottom-right
│  ○                           ○  │
└─────────────────────────────────┘
```

## Internal Layout

```
CROSS SECTION (looking from side, components laid out)

Front wall (1.0mm)
│
├── E-ink glass panel (1.2mm)
│   └── PCB / driver board (1.5mm)
│       └── FPC ribbon cable (routes to right)
│
├── [LEFT HALF]          [RIGHT HALF]
│   LiPo 300mAh flat     XIAO ESP32C3
│   40×30×2.5mm          21×17.5×3.5mm
│   (lying flat)         (USB-C faces edge notch)
│
Back wall (1.5mm) + magnet recesses
```

## Component List (per unit)

| # | Component | Spec | Source | Est. Cost |
|---|---|---|---|---|
| 1 | E-ink display | Waveshare 4.2" B&W, 400×300, SPI | Robu.in | ₹1,800 |
| 2 | MCU | Seeed XIAO ESP32C3, 21×17.5mm, built-in LiPo charge | Amazon.in | ₹600 |
| 3 | Battery | 3.7V 300mAh slim LiPo, JST-PH 2.0mm, ~2.5mm thick | MakerBazar.in | ₹150 |
| 4 | Magnets | N52 neodymium disc, 20mm×3mm (×4 per unit) | Amazon.in | ₹80 |
| 5 | Shell | White PLA, 95×115×11mm, 3D printed | Local Pune | ₹500 |
| 6 | Wires | Dupont F-F jumper wires, 10cm, 8× per unit | Robu.in | ₹30 |
| 7 | Epoxy | 2-part epoxy for magnet fixing | Hardware store | ₹20 |
| | **Total** | | | **~₹3,180** |

## Wiring Diagram

```
XIAO ESP32C3                    Waveshare 4.2" e-ink
─────────────                   ───────────────────
3.3V  ──────────────────────▶  VCC
GND   ──────────────────────▶  GND
D10 (GPIO3)  ───────────────▶  DIN  (MOSI / data in)
D8  (GPIO2)  ───────────────▶  CLK  (SPI clock)
D7  (GPIO20) ───────────────▶  CS   (chip select)
D3  (GPIO21) ───────────────▶  DC   (data/command)
D0  (GPIO9)  ───────────────▶  RST  (reset)
D1  (GPIO10) ◀──────────────   BUSY (wait signal)

XIAO BAT+ / BAT- ◀────────── JST-PH 2.0mm LiPo 300mAh
XIAO USB-C ◀──────────────── USB-C cable (charge + flash)
```

## STL Design Notes (for Tinkercad)

### Step 1 — Main body
- Start: box 95 × 115 × 11mm
- Shell it: 1.0mm front, 1.5mm back, 1.2mm sides (use shell tool)

### Step 2 — Display window (front)
- Cut rectangle: 85 × 85mm, depth 1.0mm (removes front wall)
- Position: centred horizontally, 7mm from top edge
- This exposes the display glass flush with the front face

### Step 3 — Internal bays
- Display bay: 86 × 86 × 3mm pocket from front inner face
- Component bay: 60 × 26mm footprint, 6mm deep, right-aligned
- FPC channel: 10 × 3mm slot connecting display bay to component bay

### Step 4 — Magnet pockets (back)
- 4× cylinders: 20mm diameter, 3.2mm deep (slightly deeper than magnet)
- Positions: centres at (10,10), (85,10), (10,105), (85,105) from top-left
- Cut from back face

### Step 5 — USB-C notch
- Rectangle cut: 9mm wide × 3.5mm tall
- Position: right edge of shell, 8mm from bottom
- Depth: all the way through (11mm)

### Step 6 — Front emboss (ID)
- Text "001" — 8pt equiv, 0.4mm raised from front face
- Position: bottom-left of white strip, 8mm from left, 8mm from bottom

### Step 7 — Back engrave
- Text "MEMRY v1.0" — centred, 0.3mm deep into back face, 30mm from top
- Text "for Jo" — centred below, 0.2mm deep, 8pt equivalent

### Step 8 — Export
- Export as STL (binary, mm units)
- Print orientation: front face down on print bed

## Assembly Instructions

### Before assembly — test on breadboard first
1. Wire display to XIAO using dupont jumpers per wiring diagram above
2. Flash firmware (see firmware/FIRMWARE.md)
3. Confirm display shows test image and WiFi connects
4. Only proceed to shell assembly after confirming electronics work

### Shell assembly
1. Place display face-down into front display bay
   - Display active area faces front window
   - PCB driver board faces inward
2. Route FPC ribbon cable through FPC channel into component bay
3. Place XIAO in component bay — USB-C port aligned to shell notch
4. Connect jumper wires from FPC breakout to XIAO per wiring diagram
5. Connect LiPo JST connector to XIAO BAT connector
6. Lay LiPo flat in component bay beside XIAO
7. Check nothing is pinched or shorting
8. Charge via USB-C before sealing — confirm LED behaviour on XIAO
   - Orange/red = charging, Green = full
9. Apply 2-part epoxy to magnet pockets, press N52 magnets in
   - Confirm polarity first! All magnets should attract to fridge, not each other
   - Let cure 30 minutes before handling
10. Close back shell (snap fit or M2 screws if designed with bosses)
11. Label unit: stick ID number inside back during assembly

### Testing after assembly
- Charge fully via USB-C
- Hold near fridge — confirm it sticks firmly (all 4 magnets seated)
- Upload test photo via web app
- Wait up to 4 hours for first poll (or restart device via reset button on XIAO)
- Confirm photo appears correctly on display

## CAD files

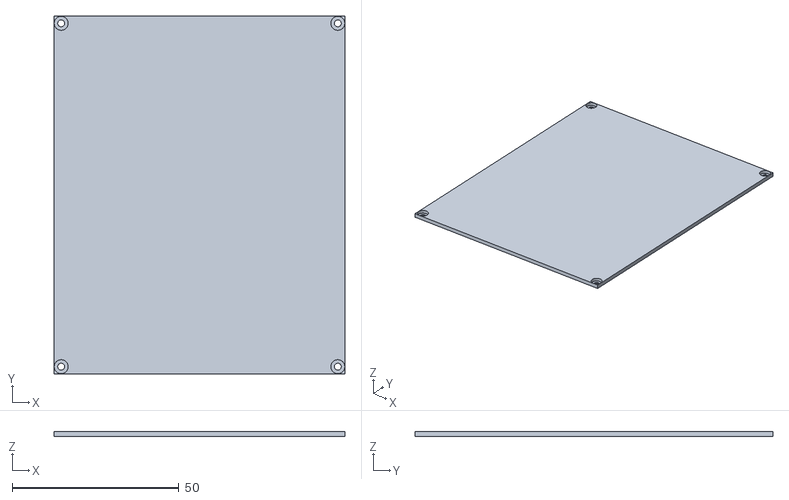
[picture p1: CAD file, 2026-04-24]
memry-shell/memry_back_panel.stl
87.3 x 107.3 x 1.50

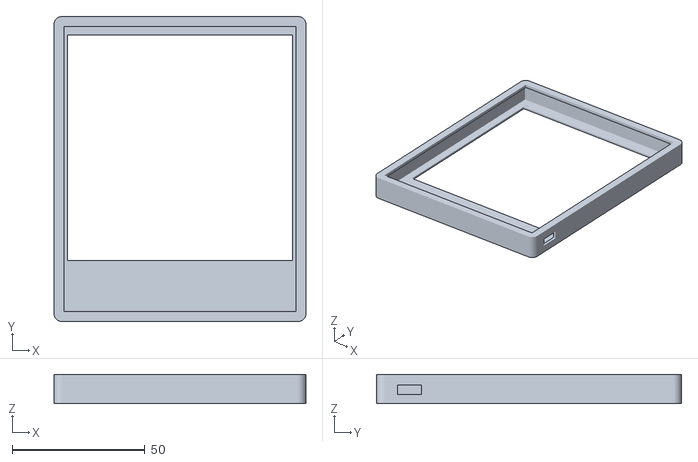
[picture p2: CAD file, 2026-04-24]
memry-shell/memry_front_panel.stl
95.0 x 115.0 x 11.0

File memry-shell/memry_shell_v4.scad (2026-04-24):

// ============================================================
// MEMRY Shell v4 — DEFINITIVE TWO-PIECE
// All geometry verified. Print-ready.
// ============================================================
//
// FRONT BODY  → front face DOWN, no supports
// BACK PANEL  → outside face DOWN, no supports
// Both: white PLA, 0.15mm layers, 3 perimeters, 20% infill
// Print 4× of each for 4 units.
//
// HARDWARE PER UNIT:
//   4× M2×6mm self-tapping screws
//   4× N52 neodymium 20mm×3mm disc magnets
//   2-part epoxy (for magnets)
//   Clear silicone sealant (for gasket groove + display edge)
//   PCB conformal coating spray (for XIAO + wiring)
//
// MAGNET POCKET (key design):
//   Magnet = 20mm dia × 3mm thick
//   Back panel has 20mm through-hole (1.5mm deep)
//   Front body rim face has 20mm blind recess (2.0mm deep)
//   Combined = 3.5mm pocket → magnet sits in, 0.5mm PLA floor
//   Epoxy from outside seals and locks magnet permanently
//   Ghost ring (raised 0.4mm) marks hole, adds grip on fridge
//
// ASSEMBLY:
//   1. Conformal coat XIAO, cure 24h
//   2. Seat display, route FPC ribbon
//   3. Seat XIAO + LiPo, wire up
//   4. Silicone bead around display window edge (inside)
//   5. Fill gasket groove with silicone sealant
//   6. Drop back panel into rim — self-locating
//   7. Drive 4× M2×6mm screws
//   8. From outside: drop magnets into ghost-ring holes
//   9. Fill with 2-part epoxy, cure 30min
// ============================================================

// ── PARAMETERS ─────────────────────────────────────────────

W  = 95;    H  = 115;   D  = 11;    // outer dims
FW = 1.0;   SW = 1.2;               // front wall, side wall

// Display window
WIN_W=85; WIN_H=85; WIN_GAP=7;

// Display bay
DBW=86; DBH=86; DBD=3.0;

// Component bay (XIAO + LiPo)
CBW=60; CBH=26; CBD=6.0;

// FPC channel
FPC_W=10; FPC_H=3;

// USB-C notch (right side)
UW=9; UH=3.5; UFB=8;

// Corner radius
CR=3.0;

// Rim ledge (front body back opening)
RIM_W=2.5;   // ledge width
RIM_H=1.5;   // ledge height = back panel thickness

// Gasket groove (on rim face)
GW=1.4; GD=1.0; GO=0.8;  // width, depth, offset from inner rim edge

// M2 screw bosses
BOD=6.5;  // boss outer dia
BID=2.1;  // screw hole dia (M2 self-tap)
BOH=7.5;  // boss height (FW to rim face = D-FW-RIM_H = 8.5mm, boss = 7.5mm)
BIN=6.0;  // boss centre inset from outer edge

// Countersink on back panel
CS_D=4.2; CS_DEP=1.2;

// Magnets: 20mm dia × 3mm thick
MAG_D  = 20;
MAG_T  = 3.0;
MAG_FL = 0.5;              // floor thickness
MAG_IN = 16.0;             // magnet centre inset from outer edge
BODY_REC = MAG_T - RIM_H + MAG_FL;  // = 2.0mm recess in front body rim face

// Ghost ring
GHR_OD = MAG_D + 3;  // 23mm outer dia
GHR_RW = 1.2;         // ring wall width
GHR_T  = 0.4;         // raised height

// Panel fit clearance
CLR = 0.15;

// ── DERIVED POSITIONS ──────────────────────────────────────

// Boss centres (global coords — same for both pieces)
BX = [BIN,    W-BIN,  BIN,    W-BIN  ];
BY = [BIN,    BIN,    H-BIN,  H-BIN  ];

// Magnet centres (global coords — same for both pieces)
MX = [MAG_IN,    W-MAG_IN,  MAG_IN,    W-MAG_IN  ];
MY = [MAG_IN,    MAG_IN,    H-MAG_IN,  H-MAG_IN  ];

// Panel bounds
PX = SW + RIM_W + CLR;
PY = SW + RIM_W + CLR;
PW = W - 2*PX;
PH = H - 2*PY;
PZ = D - RIM_H;   // panel inner face Z

// ── UTILITIES ──────────────────────────────────────────────

module rbox(w, h, d, r=CR) {
    hull()
        for (x=[r,w-r]) for (y=[r,h-r])
            translate([x,y,0]) cylinder(r=r, h=d, $fn=32);
}

// ============================================================
// PIECE 1 — FRONT BODY
// ============================================================

module front_body() {
    difference() {
        union() {
            rbox(W, H, D);
            // Screw bosses rise from above front wall to just below rim face
            for (i=[0:3])
                translate([BX[i], BY[i], FW])
                    cylinder(d=BOD, h=BOH, $fn=24);
        }

        // Hollow interior (front wall to rim face)
        translate([SW, SW, FW])
            cube([W-2*SW, H-2*SW, D-FW-RIM_H]);

        // Remove centre of back face leaving only rim band
        translate([SW+RIM_W, SW+RIM_W, D-RIM_H-0.1])
            cube([W-2*(SW+RIM_W), H-2*(SW+RIM_W), RIM_H+0.2]);

        // Display window
        translate([(W-WIN_W)/2, H-WIN_GAP-WIN_H, -0.1])
            cube([WIN_W, WIN_H, FW+0.2]);

        // Display bay
        translate([(W-DBW)/2, H-WIN_GAP-DBH, FW])
            cube([DBW, DBH, DBD]);

        // Component bay
        translate([W-SW-CBW, SW+6, FW])
            cube([CBW, CBH, CBD]);

        // FPC channel
        translate([W-SW-CBW-3, SW+6+CBH, FW])
            cube([FPC_W, 14, FPC_H]);

        // USB-C notch
        translate([W-SW-0.1, UFB, FW+(D-FW-RIM_H)/2-UH/2])
            cube([SW+0.2, UW, UH]);

        // Gasket groove on rim face
        gx = SW + GO;  gy = SW + GO;
        translate([gx, gy, D-RIM_H-0.1])
            difference() {
                cube([W-2*gx, H-2*gy, GD+0.2]);
                translate([GW, GW, -0.1])
                    cube([W-2*gx-2*GW, H-2*gy-2*GW, GD+0.4]);
            }

        // Magnet recesses in rim face (blind pocket floors)
        // 2.0mm deep from rim face into body
        for (i=[0:3])
            translate([MX[i], MY[i], D-RIM_H-BODY_REC])
                cylinder(d=MAG_D, h=BODY_REC+0.1, $fn=48);

        // Boss screw holes
        for (i=[0:3])
            translate([BX[i], BY[i], FW-0.1])
                cylinder(d=BID, h=BOH+0.2, $fn=16);
    }
}

// ============================================================
// PIECE 2 — BACK PANEL
// ============================================================

module back_panel() {
    difference() {
        union() {
            // Panel body — sits inside rim ledge
            translate([PX, PY, PZ])
                cube([PW, PH, RIM_H]);

            // Ghost rings — built on top of panel, connected to it
            // They sit directly over the magnet through-holes
            for (i=[0:3])
                translate([MX[i], MY[i], D])
                    difference() {
                        cylinder(d=GHR_OD, h=GHR_T, $fn=48);
                        // Hollow ring (the through-hole centre stays open)
                        cylinder(d=GHR_OD-2*GHR_RW, h=GHR_T+0.1, $fn=48);
                    }
        }

        // Magnet through-holes (full panel thickness)
        // Aligned to body recesses — together form complete pocket
        for (i=[0:3])
            translate([MX[i], MY[i], PZ-0.1])
                cylinder(d=MAG_D, h=RIM_H+0.2, $fn=48);

        // M2 countersinks on outside face
        for (i=[0:3]) {
            translate([BX[i], BY[i], D-CS_DEP])
                cylinder(d=CS_D, h=CS_DEP+0.1, $fn=24);
            // Screw shaft through-hole
            translate([BX[i], BY[i], PZ-0.1])
                cylinder(d=BID, h=RIM_H+0.2, $fn=16);
        }
    }
}

// ============================================================
// EXPORT
// ============================================================
// FRONT BODY STL: keep only front_body() uncommented
// BACK PANEL STL: comment front_body(), uncomment back_panel()

front_body();
// back_panel();

// Preview side by side:
// front_body();
// translate([W+15, 0, 0]) back_panel();

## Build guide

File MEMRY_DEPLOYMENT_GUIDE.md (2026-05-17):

# MEMRY — Step-by-Step Deployment & Testing Guide
**Target:** Get from code to working hardware  
**Time Estimate:** 2-3 hours for web, 3-4 hours for hardware breadboard

---

## PHASE 1: VERCEL DEPLOYMENT (~1 hour)

### Step 1.1: Apply the TypeScript Fix

**What:** Fix the type error that blocks production build

**How:**

```bash
# Navigate to your project
cd /path/to/memry/memry-web

# Open the file
# File: app/dashboard/devices/page.tsx
# Line 9
```

**Change this line:**
```typescript
function getStatus(lastRequest: string | null, sleepHours: number) {
```

**To this:**
```typescript
function getStatus(lastRequest: string | null, sleepHours: number): 'online' | 'sleeping' | 'offline' {
```

**Why:** TypeScript needs explicit return type annotation to match the `Device` interface in `DeviceListClient.tsx`.

**Verify:**
```bash
npm run build
# Should see "Compiled successfully" after type checking
# (Ignore Sharp warnings about linux-x64 runtime — those are dev-only)
```

---

### Step 1.2: Verify Supabase Setup

**What:** Confirm your existing Supabase project has the correct schema

**How:**

1. **Go to Supabase dashboard:**  
   https://app.supabase.com

2. **Select your project**

3. **Run SQL to check tables exist:**
   - Go to: SQL Editor → New query
   - Run this:
   ```sql
   SELECT table_name 
   FROM information_schema.tables 
   WHERE table_schema = 'public' 
   AND table_name IN ('devices', 'photos', 'device_settings', 'contributors', 'device_pings');
   ```

4. **Expected result:** 5 rows showing all tables

**If tables are missing:**
   - SQL Editor → New query
   - Copy entire contents of `memry-web/supabase-schema.sql`
   - Click Run
   - Wait for success message

---

### Step 1.3: Create Storage Bucket

**What:** Set up the `photos` bucket for storing processed images

**How:**

1. **In Supabase dashboard:**  
   Storage → New bucket

2. **Bucket settings:**
   - Name: `photos`
   - Public bucket: ❌ **UNCHECK** (must be private)
   - File size limit: `10 MB`
   - Allowed MIME types: 
     - `application/octet-stream`
     - `image/jpeg`
     - `image/png`

3. **Click Create**

**Verify:**
- Storage → Buckets → Should see `photos` listed as Private

---

### Step 1.4: Get Supabase API Keys

**What:** Copy the 3 environment variables needed for deployment

**How:**

1. **In Supabase dashboard:**  
   Settings → API

2. **Copy these values:**

```bash
# Project URL
https://xxxxxxxxxxxxx.supabase.co

# Public anon key (starts with eyJ...)
eyJhbGciOiJIUzI1NiIsInR5cCI6IkpXVCJ9...

# Service role key (starts with eyJ... — different from anon)
eyJhbGciOiJIUzI1NiIsInR5cCI6IkpXVCJ9...
```

**Keep these safe** — you'll paste them into Vercel in the next step.

---

### Step 1.5: Push Code to GitHub

**What:** Get your code onto GitHub so Vercel can deploy it

**How:**

**If you already have a GitHub repo at `https://github.com/zooperic/MEMRY`:**

```bash
cd /path/to/memry
git add .
git commit -m "Fix TypeScript error in devices page"
git push origin main
```

**If you DON'T have a repo yet:**

1. **Create repo on GitHub:**
   - Go to https://github.com/new
   - Repository name: `MEMRY`
   - Private or Public: Your choice
   - Don't initialize with README (you already have code)
   - Click Create

2. **Link local code to GitHub:**
```bash
cd /path/to/memry
git init
git add .
git commit -m "Initial commit: MEMRY e-ink photo frame"
git branch -M main
git remote add origin https://github.com/zooperic/MEMRY.git
git push -u origin main
```

**Verify:**  
Visit `https://github.com/zooperic/MEMRY` — you should see your files.

---

### Step 1.6: Deploy to Vercel

**What:** Import GitHub repo to Vercel and configure environment variables

**How:**

1. **Go to Vercel:**  
   https://vercel.com/new

2. **Import Git Repository:**
   - Click "Add New..." → Project
   - Select your GitHub account
   - Find `MEMRY` repository
   - Click Import

3. **Configure Project:**
   - Framework Preset: **Next.js** (auto-detected)
   - Root Directory: `memry-web` ⚠️ **CRITICAL** — your Next.js app is in a subfolder
   - Build Command: `npm run build` (default, leave as-is)
   - Install Command: `npm install` (default, leave as-is)

4. **Add Environment Variables:**
   Click "Environment Variables" section, add these 3:

   | Key | Value |
   |-----|-------|
   | `NEXT_PUBLIC_SUPABASE_URL` | `https://xxxxx.supabase.co` |
   | `NEXT_PUBLIC_SUPABASE_ANON_KEY` | `eyJhbGci...` (your anon key) |
   | `SUPABASE_SERVICE_ROLE_KEY` | `eyJhbGci...` (your service role key) |
   | `NEXT_PUBLIC_SITE_URL` | `https://memry.vercel.app` (or your custom domain) |

   **Note:** `NEXT_PUBLIC_SITE_URL` — use your Vercel deployment URL. If you don't know it yet, you can add it after first deploy (Step 1.8).

5. **Click Deploy**

**Expected result:**  
- Build starts
- Takes 2-3 minutes
- Should see "Congratulations! Your project has been deployed"

**If build fails:**
- Check the build logs
- Common issues:
  - TypeScript error (did you apply the fix from Step 1.1?)
  - Environment variables missing (did you add all 4?)
  - Root directory wrong (should be `memry-web`)

---

### Step 1.7: Note Your Deployment URL

**What:** Copy the production URL for firmware config

**How:**

1. **After successful deployment:**  
   Vercel shows your URL, typically: `https://memry-xxxxx.vercel.app`

2. **Copy this URL** — you'll need it for:
   - Firmware config (Phase 2)
   - Supabase redirect URLs (Step 1.8)

**Example:**  
`https://memry-git-main-zooperic.vercel.app`

---

### Step 1.8: Configure Supabase Authentication Redirects

**What:** Tell Supabase where to redirect users after login

**How:**

1. **In Supabase dashboard:**  
   Authentication → URL Configuration

2. **Site URL:**  
   Paste your Vercel URL: `https://memry-xxxxx.vercel.app`

3. **Redirect URLs:**  
   Add this: `https://memry-xxxxx.vercel.app/auth/callback`

4. **Click Save**

**Also update environment variable in Vercel:**
- Go to: Vercel dashboard → Your project → Settings → Environment Variables
- Find `NEXT_PUBLIC_SITE_URL`
- Click Edit
- Paste your Vercel URL
- Click Save
- **Redeploy:** Deployments → Click "..." on latest → Redeploy

---

### Step 1.9: Test Web Portal

**What:** Verify the deployed app works end-to-end

**How:**

1. **Open your Vercel URL:**  
   `https://memry-xxxxx.vercel.app`

2. **Sign up flow:**
   - Click Sign In
   - Enter email + password
   - Should redirect to `/dashboard`

3. **Pair a test device:**
   - Dashboard → "Pair a device"
   - Device ID: `test-001`
   - Device name: `Test Fridge`
   - Click Save

4. **Upload a test photo:**
   - Dashboard → Select `test-001` → Upload
   - Choose any photo from your computer
   - Adjust settings if you want
   - Click "Process & Upload"
   - Wait ~5 seconds for processing
   - Should see success message

5. **Activate the photo:**
   - Go to Library (for `test-001`)
   - Click the uploaded photo
   - Click "Set as Active"

6. **Test the device API endpoint:**
   - Open a new browser tab
   - Go to: `https://memry-xxxxx.vercel.app/api/device/test-001/current-image`
   - **Expected:** Should download a BMP file (or show binary data)
   - **If 404:** Photo isn't active — go back to Library and activate it

**Checklist:**
- [ ] Landing page loads
- [ ] Sign up works
- [ ] Dashboard loads with device grid
- [ ] Can pair a device
- [ ] Can upload a photo
- [ ] Photo appears in Library
- [ ] Can activate a photo
- [ ] Device API returns BMP data

**If any step fails:**
- Check browser console for errors (F12 → Console)
- Check Vercel logs (Vercel dashboard → Deployments → Your deployment → Logs)
- Check Supabase logs (Supabase dashboard → Database → Logs)

---

## ✅ PHASE 1 COMPLETE

**You now have:**
- ✅ Working web portal at a public URL
- ✅ Supabase backend with schema + storage
- ✅ Device API endpoint that returns BMP images
- ✅ Test device paired and photo uploaded

**Save this URL** — you'll need it for Phase 2 (firmware config).

---

## PHASE 2: HARDWARE BREADBOARD TEST (~3-4 hours)

**⚠️ CRITICAL:** Do NOT skip this. You have **one display, one ESP32**. If you assemble without testing, and something is wrong, you'll have to disassemble a sealed, epoxied unit.

---

### Step 2.1: Gather Components

**Required hardware:**

| Qty | Component | Notes |
|-----|---|---|
| 1× | Waveshare 3.6" e-Paper HAT+ (E) | SKU 32650, Spectra 6, 600×400 |
| 1× | Seeed XIAO ESP32C3 | |
| 1× | 300mAh LiPo battery | JST-PH 2.0mm connector |
| 8× | Female-to-Female dupont jumpers | 10-20cm length |
| 1× | USB-C cable | For programming + power |
| 1× | Breadboard (optional) | For stability, or tape to desk |

**Optional but recommended:**
- Multimeter (for measuring battery voltage + current)
- USB power meter (to verify deep sleep current)

**Where to buy (if you don't have yet):**
- **Display:** https://www.waveshare.com/product/3.6inch-e-paper-hat-e.htm
- **XIAO ESP32C3:** https://www.seeedstudio.com/Seeed-XIAO-ESP32C3-p-5431.html
- **Battery:** Any 300-500mAh LiPo with JST-PH 2.0mm (search "300mah jst 2.0")

---

### Step 2.2: Physical Wiring

**CRITICAL CHECKS BEFORE WIRING:**

1. **Display interface switch:** Find the small DIP switch on the HAT+ PCB. It MUST be set to position **0** (4-line SPI). If it's on 1, 2, or 3, the display won't work.

2. **PWR pin:** The display has a PWR pin that MUST be tied to 3.3V. This is NOT optional. Without it, the display stays dark. This is the #1 reason breadboard tests fail.

**Wiring Table:**

| Display Pin | XIAO ESP32C3 Pin | Function | Recommended Wire Color |
|---|---|---|---|
| VCC | 3.3V | Power supply | Red |
| GND | GND | Ground | Black |
| DIN | D10 (GPIO3) | SPI MOSI | Blue |
| CLK | D8 (GPIO2) | SPI SCK | Yellow |
| CS | D7 (GPIO20) | Chip select | Green |
| DC | D3 (GPIO21) | Data/Command | Orange |
| RST | D0 (GPIO9) | Reset | Purple |
| BUSY | D1 (GPIO10) | Busy signal (input) | White |
| **PWR** | **3.3V** | **CRITICAL!** | **Red jumper** |

**Step-by-step wiring:**

1. **Lay out components:**
   - Display HAT on desk (or breadboard)
   - XIAO ESP32C3 nearby
   - Don't connect battery or USB yet

2. **Wire power first:**
   - Display **VCC** → XIAO **3.3V** (red wire)
   - Display **GND** → XIAO **GND** (black wire)
   - Display **PWR** → XIAO **3.3V** (second red wire or jumper)

3. **Wire SPI signals:**
   - Follow table above for remaining 6 connections
   - Double-check each connection

4. **Visual inspection:**
   - Count wires: Should have **9 physical connections** (8 wires + PWR tie)
   - Verify PWR is tied to 3.3V (not floating, not GND)
   - Verify interface switch is at position 0

5. **Take a photo of your wiring** (for reference during assembly)

**Common mistakes:**
- ❌ Forgot to tie PWR to 3.3V → display stays blank
- ❌ Interface switch on wrong position → garbage data
- ❌ CS pin connected to wrong GPIO → SPI won't work
- ❌ Reversed VCC/GND → smoke (don't do this!)

---

### Step 2.3: Install Arduino IDE & ESP32 Support

**What:** Set up development environment for flashing firmware

**How:**

1. **Download Arduino IDE 2.x:**  
   https://www.arduino.cc/en/software  
   Install for your OS (Windows/Mac/Linux)

2. **Add ESP32 board support:**
   - Open Arduino IDE
   - File → Preferences
   - Find: "Additional Board Manager URLs"
   - Paste this URL:
     ```
     https://raw.githubusercontent.com/espressif/arduino-esp32/gh-pages/package_esp32_index.json
     ```
   - Click OK

3. **Install ESP32 boards:**
   - Tools → Board → Boards Manager
   - Search: `esp32`
   - Find: "esp32 by Espressif Systems"
   - Click Install (downloads ~200MB, takes 2-3 minutes)

4. **Select XIAO ESP32C3 board:**
   - Tools → Board → esp32 → **XIAO_ESP32C3**

5. **Install required library:**
   - Tools → Manage Libraries
   - Search: `ArduinoJson`
   - Install: "ArduinoJson by Benoit Blanchon" (v6.x or v7.x, either works)

**Verify setup:**
- Tools → Board → Should say "XIAO_ESP32C3"
- Tools → Manage Libraries → Search "ArduinoJson" → Should show "INSTALLED"

---

### Step 2.4: Update Firmware Config

**What:** Point firmware to your deployed Vercel URL

**How:**

1. **Open config file:**
   - Navigate to: `memry/memry-firmware/config.h`
   - Open in any text editor

2. **Update SERVER_URL:**

**Change line 18 from:**
```cpp
#define SERVER_URL    "http://192.168.1.42:3001"
```

**To your Vercel URL:**
```cpp
#define SERVER_URL    "https://memry-xxxxx.vercel.app"
```

**⚠️ Important:**
- Remove `http://` and replace with `https://`
- Remove any trailing slashes
- Remove any `/api` or other path segments
- Just the base domain

**Example:**
```cpp
#define SERVER_URL    "https://memry-git-main-zooperic.vercel.app"
```

3. **Verify DEVICE_ID:**

Line 13 should be:
```cpp
#define DEVICE_ID     "memry-001"
```

**This MUST match the device ID you paired in the web portal in Step 1.9.**

If you used a different ID (like `test-001`), change it:
```cpp
#define DEVICE_ID     "test-001"
```

4. **Save the file**

**Why this matters:**
- Firmware fetches images from: `SERVER_URL + /api/device/ + DEVICE_ID + /current-image`
- If these don't match your web portal, the fetch will 404

---

### Step 2.5: Flash Firmware to ESP32

**What:** Upload the firmware to your XIAO ESP32C3

**How:**

1. **Connect XIAO to computer:**
   - Plug USB-C cable into XIAO
   - Plug other end into computer
   - XIAO LED should light up (red or green)

2. **Select serial port:**
   - Arduino IDE → Tools → Port
   - Should see a new port appear (e.g., `/dev/ttyUSB0` on Linux, `COM3` on Windows)
   - Select it

3. **Open firmware:**
   - File → Open
   - Navigate to: `memry/memry-firmware/memry.ino`
   - Click Open

4. **Verify code compiles:**
   - Click ✓ (Verify) button
   - Wait 10-20 seconds
   - Should see "Compilation complete" at bottom

**If compilation fails:**
- Check error message
- Common issues:
  - Board not selected (Tools → Board → XIAO_ESP32C3)
  - ArduinoJson not installed (Tools → Manage Libraries)
  - Wrong Arduino IDE version (need 2.x)

5. **Upload firmware:**
   - Click → (Upload) button
   - Wait 30-60 seconds
   - Progress bar shows: "Connecting...", "Writing...", "Verifying..."
   - Should see "Done uploading" at bottom

**If upload fails:**
- Try putting XIAO into boot mode:
  - Hold BOOT button
  - Press RESET button
  - Release RESET
  - Release BOOT
  - Try upload again

6. **Open Serial Monitor:**
   - Tools → Serial Monitor
   - Set baud rate: **115200**
   - Should see output like:
     ```
     ── MEMRY wake #1  device=test-001 ──
     No WiFi creds — starting provisioning portal
     ```

---

### Step 2.6: WiFi Provisioning (First Boot)

**What:** Give the device your WiFi credentials via captive portal

**Expected behavior on first boot:**
- Device creates its own WiFi network: `MEMRY-SETUP-XXXX`
- Display shows: "WiFi Setup" or "Connect to MEMRY-SETUP"

**How:**

1. **On your phone or laptop:**
   - Go to WiFi settings
   - Look for network: `MEMRY-SETUP-XXXX` (XXXX = last 4 hex digits of MAC)
   - Connect to it (no password needed)

2. **Captive portal should auto-open:**
   - If not, open browser and go to: `192.168.4.1`

3. **Enter WiFi credentials:**
   - SSID: Your home WiFi name
   - Password: Your WiFi password
   - Click Submit

4. **Device reboots:**
   - Disconnects from setup network
   - Connects to your WiFi
   - Should see in Serial Monitor:
     ```
     WiFi connected: 192.168.1.123
     Fetching https://memry-xxxxx.vercel.app/api/device/test-001/current-image
     ```

**If provisioning fails:**
- Can't see `MEMRY-SETUP-XXXX` network:
  - Check Serial Monitor for errors
  - Press RESET button on XIAO to restart
  - Wait 10 seconds for network to appear

- Portal won't open:
  - Some phones/laptops block captive portals
  - Manually go to: `http://192.168.4.1`

- WiFi credentials rejected:
  - Check for typos in SSID/password
  - Some special characters may not work
  - Try a simpler WiFi password if possible

---

### Step 2.7: First Fetch & Render Test

**What:** Verify device can fetch from API and render to display

**Expected behavior after WiFi connects:**

1. **Serial Monitor output:**
   ```
   ── MEMRY wake #1  device=test-001 ──
   WiFi connected: 192.168.1.123
   Battery: 4123mV
   Fetching https://memry-xxxxx.vercel.app/api/device/test-001/current-image
   → 200 OK (123456 bytes)
   → ETag: abc123...
   Rendering image...
   EPD init...
   EPD refresh (19 seconds)...
   EPD sleep
   Deep sleep for 4 hours
   ```

2. **Display behavior:**
   - Display should start flickering (normal for e-ink refresh)
   - Color sequence: Black → Red → Yellow → etc. (Spectra 6 refresh cycle)
   - Refresh takes ~19 seconds
   - Final image appears
   - Display goes static (deep sleep)

3. **Verify image:**
   - Should see the photo you uploaded in Step 1.9
   - Check orientation (should be portrait, not rotated)
   - Check colors (6-color Spectra 6 palette)
   - Check for dithering quality (Floyd-Steinberg should smooth gradients)

**If display stays blank:**

**Most likely cause: PWR pin not connected**
- Check wiring: PWR → 3.3V jumper in place?
- Measure with multimeter: PWR pin should read 3.3V

**Other causes:**
- Interface switch wrong position → Set to 0
- Wrong pins → Double-check wiring table
- Display defective → Try different SPI pins (update config.h)

**If display shows garbage/wrong colors:**
- Color palette wrong → Check `epd3in6e_driver.h` matches Spectra 6
- Partial update issue → Need full refresh, check LUT table

**If API fetch fails (404 or connection error):**
- Check Serial Monitor error
- Verify `SERVER_URL` in config.h
- Verify `DEVICE_ID` matches web portal
- Test API manually in browser: `https://memry-xxx.vercel.app/api/device/test-001/current-image`
- Check Vercel logs for errors

---

### Step 2.8: Deep Sleep Test

**What:** Verify device actually goes to deep sleep and wakes up

**Why this matters:**  
If deep sleep fails, battery drains in hours instead of months.

**How:**

1. **Wait for device to sleep:**
   - After first render, Serial Monitor shows: "Deep sleep for 4 hours"
   - XIAO LED turns off
   - Display stays static

2. **Check current consumption (if you have USB power meter):**
   - Disconnect USB from computer
   - Connect: Wall charger → USB power meter → USB-C → XIAO
   - Should read: **<1mA** (ideally 0.05-0.2mA)
   - **If >10mA:** Deep sleep isn't working

3. **Test wake-on-RESET:**
   - Press RESET button on XIAO
   - Device should wake up
   - Serial Monitor shows: `── MEMRY wake #2 ...`
   - Fetches from API again
   - Checks ETag (if same image, skips render)
   - Goes back to sleep

4. **ETag cache test:**
   - First wake: Renders image (ETag stored in RTC memory)
   - Second wake: Fetches, sees same ETag, skips render
   - Serial Monitor should show:
     ```
     → ETag unchanged, skipping render
     Deep sleep for 4 hours
     ```

**Checklist:**
- [ ] Device wakes on RESET button press
- [ ] Serial Monitor shows incrementing wake count
- [ ] ETag check works (skips render on second wake)
- [ ] Current consumption <1mA during sleep (if measurable)

**If deep sleep fails (current >10mA):**
- Display not in sleep mode → Check `epdSleep()` is called
- WiFi not disconnected → Check `WiFi.disconnect(true)` in code
- Peripheral leakage → May need to add `esp_sleep_pd_config()` calls

---

### Step 2.9: Upload New Photo & Test Update

**What:** Verify device fetches and renders a new photo

**How:**

1. **While device is asleep, upload a new photo:**
   - Go to web portal: `https://memry-xxxxx.vercel.app`
   - Dashboard → Upload (for `test-001`)
   - Upload a **different photo** (so you can tell it changed)
   - Click "Process & Upload"
   - Go to Library → Click new photo → "Set as Active"

2. **Wake device:**
   - Press RESET button on XIAO
   - Watch Serial Monitor

3. **Expected behavior:**
   - Fetches from API
   - ETag is different (new photo)
   - Renders new image to display (~19 seconds)
   - Display shows the NEW photo
   - Goes back to sleep

**Verify:**
- [ ] Display updated to show new photo
- [ ] Old photo is gone
- [ ] New photo is correctly oriented
- [ ] Colors look good

**If device doesn't fetch new photo:**
- Check Serial Monitor for errors
- Verify photo is marked "active" in web portal
- Test API in browser (should return new BMP)

---

### Step 2.10: Battery Test

**What:** Verify device works on battery power (no USB)

**How:**

1. **Connect battery:**
   - Plug LiPo JST connector into XIAO battery port
   - **Do NOT connect USB at the same time** (can damage battery)

2. **Measure battery voltage (if you have multimeter):**
   - Touch red probe to BAT+ terminal
   - Touch black probe to GND terminal
   - Should read: **3.7-4.2V** (fully charged)
   - **If <3.0V:** Battery is dead, charge via USB first

3. **Test wake cycle on battery:**
   - Press RESET button
   - Device should wake, fetch, render, sleep
   - **No USB connected** — running purely on battery

4. **Estimate battery life:**
   - If you have a USB power meter:
     - Connect: Battery → XIAO → USB meter → dummy load
     - Measure current during:
       - Deep sleep: Should be <1mA (0.05-0.2mA ideal)
       - WiFi active: ~80-150mA
       - Display refresh: ~100-200mA
   - Calculate runtime:
     - Assume 4hr sleep cycle
     - Wake time per cycle: ~30 seconds (WiFi + fetch + render)
     - Sleep time per cycle: ~3.99 hours
     - Average current = (150mA × 30s + 0.2mA × 14370s) / 14400s ≈ **0.5mA**
     - 300mAh / 0.5mA ≈ **600 hours ≈ 25 days**

**Realistic battery life:**
- Best case (everything perfect): 2-3 months
- Typical (some leakage): 3-4 weeks
- Worst case (deep sleep broken): 2-3 days

**If battery drains fast:**
- Check deep sleep current (should be <1mA)
- Check for peripheral leakage (display, WiFi, SPI)
- May need to add power domain config in firmware

---

### Step 2.11: Breadboard Test Checklist

**Before proceeding to assembly, verify ALL of these:**

**Physical:**
- [ ] Display has 9 connections (8 wires + PWR tie to 3.3V)
- [ ] Interface switch is at position 0
- [ ] All dupont connections are firm (not loose)
- [ ] Photo of wiring saved for assembly reference

**Firmware:**
- [ ] WiFi provisioning works (can connect to home WiFi)
- [ ] API fetch works (returns 200 OK)
- [ ] Display renders correctly (shows uploaded photo)
- [ ] Colors are correct (6-color Spectra 6 palette)
- [ ] Orientation is correct (portrait, not landscape)

**Power:**
- [ ] Device wakes on RESET button press
- [ ] Deep sleep works (current <1mA)
- [ ] ETag caching works (skips render when image unchanged)
- [ ] Battery powers device (no USB needed)
- [ ] Battery voltage is healthy (>3.5V)

**API Integration:**
- [ ] Fetches from correct URL (Vercel deployment)
- [ ] Returns BMP data (not 404 or error)
- [ ] New photos trigger display update
- [ ] Serial Monitor shows no errors

**If ANY item fails:**
- ❌ **DO NOT proceed to assembly**
- Debug on breadboard first
- Assembling with known issues = disaster

**If ALL items pass:**
- ✅ **Ready for assembly** (Phase 3)
- Take final photos of working breadboard
- Label all wires before disassembly

---

## ✅ PHASE 2 COMPLETE

**You now have:**
- ✅ Working hardware on breadboard
- ✅ Verified end-to-end flow (upload → API → ESP32 → display)
- ✅ Confirmed power consumption is acceptable
- ✅ Proven the firmware works with your Vercel deployment

**Next:** Proceed to Phase 3 (Assembly) — but only if breadboard test is 100% successful.

---

## PHASE 3: TROUBLESHOOTING GUIDE

### Display Issues

| Symptom | Cause | Fix |
|---|---|-----|
| Display completely blank | PWR not tied to 3.3V | Add jumper: PWR → 3.3V |
| Display blank | Interface switch wrong | Set to position 0 |
| Display blank | Wrong pin connections | Check wiring table |
| Garbage/random pixels | Wrong color palette | Check epd3in6e_driver.h |
| Wrong colors | Display type mismatch | Verify Spectra 6 (SKU 32650) |
| Partial update artifacts | LUT table issue | Need full refresh code |
| Image rotated 90° | Rotation not set | Add `setRotation(1)` in driver |
| Image upside down | Rotation wrong direction | Try `setRotation(3)` |

### WiFi Issues

| Symptom | Cause | Fix |
|---|---|-----|
| Can't see MEMRY-SETUP network | AP mode failed | Check Serial Monitor for errors |
| Portal won't open | Phone blocked captive | Go to 192.168.4.1 manually |
| WiFi credentials rejected | Wrong SSID/password | Double-check for typos |
| WiFi connects but fetch fails | Wrong SERVER_URL | Check config.h |
| Intermittent WiFi drops | Signal strength | Move closer to router |
| WiFi never connects | Timeout too short | Increase WIFI_TIMEOUT_MS |

### API Issues

| Symptom | Cause | Fix |
|---|---|-----|
| 404 Not Found | DEVICE_ID mismatch | Check config.h vs web portal |
| 404 Not Found | No active photo | Set a photo as active in Library |
| Connection timeout | Wrong URL | Verify SERVER_URL (https, not http) |
| SSL error | Certificate issue | ESP32 doesn't validate certs, shouldn't happen |
| ETag not working | Server cache | Clear Vercel cache and redeploy |
| Image corrupted | BMP header wrong | Check imageProcess.ts pipeline |

### Power Issues

| Symptom | Cause | Fix |
|---|---|-----|
| Deep sleep current >10mA | Display not sleeping | Check epdSleep() is called |
| Deep sleep current >10mA | WiFi not disconnected | Add WiFi.disconnect(true) |
| Device won't wake | Battery dead | Charge via USB-C |
| Device won't wake | Deep sleep config wrong | Check esp_deep_sleep_start() |
| Battery drains in days | Deep sleep broken | Measure current, debug power domains |
| USB and battery conflict | Both connected | Never connect both simultaneously |

### Firmware Issues

| Symptom | Cause | Fix |
|---|---|-----|
| Compilation error | Library missing | Install ArduinoJson |
| Upload error | Wrong board selected | Tools → Board → XIAO_ESP32C3 |
| Upload error | Wrong port | Tools → Port → Select USB port |
| Serial Monitor blank | Wrong baud rate | Set to 115200 |
| Infinite reset loop | Watchdog timeout | Check for long-running code |
| RTC memory lost | Power cycled | Expected, re-provision WiFi |

---

## PHASE 4: NEXT ACTIONS

### After Breadboard Test Passes

**DO THIS:**
1. ✅ Take photos of working breadboard setup
2. ✅ Label wires with tape (which pin goes where)
3. ✅ Test one more time to be sure
4. ✅ Proceed to shell update (if not done yet)
5. ✅ Order shell prints (or assemble if prints ready)

**DON'T DO THIS:**
- ❌ Assemble without confirming breadboard works
- ❌ Skip deep sleep test (battery will die)
- ❌ Assume wiring will be the same during assembly (take photos!)

### Shell Update (Can Do Anytime)

**If you haven't updated the shell STL yet:**

1. Open: `memry/memry-shell/memry_shell_v4.scad`
2. Find line with `WINDOW_H = 85;`
3. Change to: `WINDOW_H = 58;`
4. Re-export STLs
5. Print 2× sets (one spare)

**Why:** Current window is too tall for Spectra 6 display. Will expose 28mm of black border.

---

## ESTIMATED TIMELINE

**Completed today:**
- ✅ Phase 1: Vercel deployment (1 hour)

**Tomorrow:**
- ⏳ Phase 2: Breadboard test (3-4 hours)

**Next week:**
- ⏳ Shell prints arrive (if ordered)
- ⏳ Assembly (2-3 hours)
- ⏳ 24-hour burn-in test

**Total time to working unit:** ~1 week (assuming prints arrive)

---

## FINAL CHECKLIST BEFORE ASSEMBLY

**Web Portal:**
- [ ] Deployed to Vercel
- [ ] Supabase schema applied
- [ ] Storage bucket created
- [ ] Test device paired
- [ ] Test photo uploaded and active
- [ ] Device API returns BMP

**Hardware:**
- [ ] Breadboard test 100% successful
- [ ] Display renders correctly
- [ ] WiFi provisioning works
- [ ] Deep sleep current <1mA
- [ ] Battery powers device
- [ ] Photos of wiring taken

**Firmware:**
- [ ] SERVER_URL points to Vercel
- [ ] DEVICE_ID matches web portal
- [ ] ArduinoJson library installed
- [ ] Compiles without errors
- [ ] No Serial Monitor errors

**Shell:**
- [ ] Window dimensions updated (85×58mm)
- [ ] STLs exported
- [ ] Prints ordered (2× sets)
- [ ] Prints received and verified

**If any box is unchecked:**
- ❌ **DO NOT ASSEMBLE**

**If all boxes are checked:**
- ✅ **Ready for assembly**

---

**Guide Complete.**

Start with Phase 1 (Vercel deployment), then Phase 2 (breadboard test). Once breadboard is confirmed working, we'll create the assembly guide (Phase 3).

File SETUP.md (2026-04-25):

# MEMRY — Setup Guide
*From components to a working fridge magnet. Every step.*

---

## What you're building

Four WiFi e-ink fridge magnets (Polaroid form factor) that display photos from a web portal. The stack:

- **Hardware:** Seeed XIAO ESP32C3 + Waveshare 3.6" Spectra 6 e-ink display + 300mAh LiPo
- **Firmware:** Arduino C++ in `memry-firmware/`
- **Web portal:** Next.js 14 in `memry-web/`
- **Backend:** Supabase (auth + Postgres + storage) — free tier is enough
- **Hosting:** Vercel — free tier is enough

---

## Part 1 — Supabase (15 min)

### 1.1 Create project
1. Go to [supabase.com](https://supabase.com) → sign in with GitHub → **New project**
2. Name: `memry`, region: **Southeast Asia (Singapore)** — closest to Pune
3. Wait ~2 min for provisioning

### 1.2 Get your credentials
**Settings → API** (left sidebar):

| What | Where in dashboard | Env var name |
|---|---|---|
| Project URL | "Project URL" | `NEXT_PUBLIC_SUPABASE_URL` |
| Anon key | "anon public" key | `NEXT_PUBLIC_SUPABASE_ANON_KEY` |
| Service role key | "service_role" key (click reveal) | `SUPABASE_SERVICE_ROLE_KEY` |

### 1.3 Run the database schema
**SQL Editor → New query** → paste entire contents of `memry-web/supabase-schema.sql` → **Run**

You should see: *"Success. No rows returned."*

### 1.4 Create storage bucket
**Storage → New bucket:**
- Name: `photos`
- Public: **OFF**
- File size limit: `10 MB`
- Allowed MIME types: `application/octet-stream,image/jpeg,image/png,image/webp`

### 1.5 Configure auth redirect (for local dev)
**Authentication → URL Configuration:**
- Site URL: `http://localhost:3000`
- Redirect URLs: `http://localhost:3000/auth/callback`

---

## Part 2 — Web portal locally (10 min)

```bash
cd memry-web
npm install
cp .env.local.example .env.local
```

Open `.env.local` and fill in the three values from Step 1.2 + your site URL:

```env
NEXT_PUBLIC_SUPABASE_URL=https://xxxxxxxxxxxx.supabase.co
NEXT_PUBLIC_SUPABASE_ANON_KEY=eyJhbGci...
SUPABASE_SERVICE_ROLE_KEY=eyJhbGci...
NEXT_PUBLIC_SITE_URL=http://localhost:3000
```

```bash
npm run dev
# → http://localhost:3000
```

### First login
1. Go to `/auth` → **Create account** → enter email + password
2. Check email for confirmation link (if it doesn't arrive: Supabase → Authentication → Users → find your email → 3 dots → **Send confirmation email**)
3. Confirm → you'll land on the dashboard

### Fix the one known bug before pairing
In `memry-web/app/api/device/[id]/route.ts`, find two lines:
```ts
.select('id, processed_path')      // line ~68
.download(photo.processed_path)    // line ~99
```
Change both to `storage_path`. This is a column name mismatch — without it the device gets a 502.

---

## Part 3 — Deploying the web portal (20 min)

### 3.1 Push to GitHub
```bash
cd memry-web   # or the MEMRY root if you want the whole repo
git init
git add .
git commit -m "initial"
git remote add origin https://github.com/YOUR_USERNAME/memry.git
git push -u origin main
```

### 3.2 Deploy to Vercel
1. Go to [vercel.com](https://vercel.com) → **Add New Project** → import your GitHub repo
2. **Root Directory:** set to `memry-web` (since that's where `package.json` is)
3. **Environment Variables** — add the same four from `.env.local`:
   - `NEXT_PUBLIC_SUPABASE_URL`
   - `NEXT_PUBLIC_SUPABASE_ANON_KEY`
   - `SUPABASE_SERVICE_ROLE_KEY`
   - `NEXT_PUBLIC_SITE_URL` → set to your Vercel URL, e.g. `https://memry-web.vercel.app`
4. **Deploy**

### 3.3 Update Supabase for production
After you have the Vercel URL, go back to Supabase:
**Authentication → URL Configuration** → add your Vercel URL:
- Site URL: `https://memry-web.vercel.app`
- Redirect URLs: `https://memry-web.vercel.app/auth/callback`

### 3.4 Set up CI/CD (optional but recommended)
The repo already has `.github/workflows/ci.yml`. To activate it:

Go to your GitHub repo → **Settings → Secrets and variables → Actions** → add:

| Secret | Value |
|---|---|
| `NEXT_PUBLIC_SUPABASE_URL` | Your Supabase URL |
| `NEXT_PUBLIC_SUPABASE_ANON_KEY` | Your anon key |
| `SUPABASE_SERVICE_ROLE_KEY` | Your service role key |
| `NEXT_PUBLIC_SITE_URL` | Your Vercel URL |
| `VERCEL_TOKEN` | vercel.com → Account Settings → Tokens → Create |

After this: every `git push` to `main` auto-deploys. Every PR gets a preview URL.

---

## Part 4 — Hardware assembly

### What you need
- Seeed XIAO ESP32C3
- Waveshare 3.6" E Ink Spectra 6 display + HAT+ breakout board (SKU 32650)
- 300mAh LiPo, JST-PH 2.0mm connector
- Dupont F-F jumper wires
- Breadboard (for initial testing — no soldering yet)

### Wiring (breadboard first)

```
HAT+ breakout pin  →  XIAO ESP32C3 pin
────────────────────────────────────────
GND                →  GND
VCC                →  3.3V
PWR                →  3.3V  ← critical, display stays dark without it
DIN (MOSI)         →  D10  (GPIO3)
CLK (SCK)          →  D8   (GPIO2)
CS                 →  D7   (GPIO20)
DC                 →  D3   (GPIO21)
RST                →  D0   (GPIO9)
BUSY               →  D1   (GPIO10)
```

Use the **9-pin breakout connector on the right side** of the HAT+ board, not the 40-pin Pi header.

Check the small **interface switch** on the HAT+ PCB — it must be at position **0** (4-line SPI).

LiPo connects to the XIAO's JST-PH 2.0mm battery connector (BAT+ / BAT−). Charging happens via USB-C on the XIAO.

---

## Part 5 — Firmware setup

### 5.1 Arduino IDE
1. Install [Arduino IDE 2.x](https://www.arduino.cc/en/software)
2. **Preferences → Additional boards manager URLs** → add:
   ```
   https://raw.githubusercontent.com/espressif/arduino-esp32/gh-pages/package_esp32_index.json
   ```
3. **Tools → Board Manager** → search `esp32` → install **esp32 by Espressif Systems** (v3.x)
4. **Tools → Manage Libraries** → install **ArduinoJson** by Benoit Blanchon (v6.x)
5. Select board: **Tools → Board → ESP32C3 Dev Module**
   - (If "XIAO_ESP32C3" appears as an option, use that instead)

### 5.2 Configure per device
Open `memry-firmware/config.h`. Change these two lines per unit:

```cpp
#define DEVICE_ID  "memry-001"   // Change to 001, 002, 003, 004 for each unit

// During local dev (use your Mac's LAN IP, not localhost):
#define SERVER_URL "http://192.168.x.x:3000"

// Once deployed to Vercel:
// #define SERVER_URL "https://memry-web.vercel.app"
```

Find your Mac's LAN IP: **System Settings → WiFi → Details → IP Address**

### 5.3 Flash
1. Connect XIAO via USB-C
2. **Tools → Port** → select the XIAO port
3. Upload (Cmd+U)
4. Open Serial Monitor at **115200 baud**

### 5.4 First boot — WiFi provisioning
The device has no WiFi credentials, so it launches a setup portal:

1. The e-ink display shows setup instructions and the device ID
2. On your phone: **WiFi settings → connect to `memry-setup`**
3. A captive portal page opens automatically
4. Enter your home WiFi name + password → Save
5. Device restarts, connects to WiFi, polls the server

---

## Part 6 — First end-to-end test

Before the device fetches its first image you need:

1. `npm run dev` running on your laptop (or Vercel deployed)
2. A device paired in the web app:
   - Dashboard → **Pair device** → enter the 3-digit number (e.g. `001`) → name it → confirm
3. A photo uploaded and set active:
   - Dashboard → **Upload photo** → drop a photo → adjust → **Send to fridge**

Then watch the Serial Monitor on the ESP32:

```
── MEMRY wake #1  device=memry-001 ──
WiFi connected: 192.168.1.x
Battery: 3850mV
Fetching http://192.168.1.42:3000/api/device/memry-001/current-image
HTTP 200
New image — 120000 bytes, ETag: "memry-abc123..."
EPD rendering rotated 120000 bytes (400×600)...
EPD refreshing rotated (this takes ~19s)...
EPD render done in 19243ms
Sleeping 4h...
```

The display will flash through colours then settle on your photo. **~19 seconds is normal** for Spectra 6 — it's doing a full 6-colour refresh.

---

## Part 7 — Shell assembly (after firmware confirmed working)

Order of operations per unit:

1. **Breadboard test** — confirm display + XIAO + LiPo work on the bench
2. **Conformal coat** — spray XIAO + all solder joints, cure 24h
3. **Seat display** — place face-down in display bay, route FPC ribbon
4. **Seal display edge** — thin silicone bead around window perimeter (inside)
5. **Seat XIAO + LiPo** — component bay, connect FPC jumpers + JST battery
6. **Fill gasket groove** — clear silicone into rim groove
7. **Back panel** — self-locates inside rim ledge, press evenly
8. **4× M2×6mm screws** — corners, firm but don't overtighten
9. **Insert magnets** — N52 20mm×3mm discs into ghost-ring holes from outside
10. **Epoxy magnets** — fill with 2-part epoxy, cure 30 min

---

## Troubleshooting

| Symptom | Fix |
|---|---|
| Display stays blank | PWR pin not connected to 3.3V |
| `EPD BUSY timeout` in serial | RST or BUSY wires swapped; wrong pin |
| `HTTP -1` / connection refused | Wrong IP in `SERVER_URL`, or `npm run dev` not running |
| `HTTP 404` | Device ID in `config.h` doesn't match what you paired in the app |
| `HTTP 502` | Apply the `storage_path` fix in `app/api/device/[id]/route.ts` |
| Provisioning portal doesn't open | Phone reconnected to home WiFi — disable auto-join temporarily |
| Photo looks stretched | Upload page crops to square — use zoom/pan controls before sending |
| Image very dark/light | Use brightness/contrast sliders in upload editor |

---

## Device API contract (for reference)

```
GET /api/device/{id}/current-image

Device sends:
  If-None-Match: "memry-{photo_uuid}"   ← ETag from last fetch (RTC memory)
  X-Battery-Mv: 3850                    ← ADC reading

Server responds:
  200  → 120,000 bytes raw 4bpp binary
         ETag: "memry-{photo_uuid}"
         X-Sleep-Hours: 4

  304  → empty body (image unchanged, skip render)
         ETag: "memry-{photo_uuid}"
         X-Sleep-Hours: 4

  404  → no active photo yet, sleep and retry
```

Image format: 4bpp packed, 600×400 landscape. Device rotates 90° CW on render.
Colour palette: Black=0x0 White=0x1 Green=0x2 Blue=0x3 Red=0x4 Yellow=0x5

---

## File structure

```
MEMRY/
├── SETUP.md                    ← you are here
├── ARCHITECTURE.md             ← system design details
├── ROADMAP.md                  ← milestone tracker
├── memry-firmware/
│   ├── memry.ino               ← main sketch
│   ├── config.h                ← change DEVICE_ID + SERVER_URL per unit
│   ├── epd3in6e_driver.h       ← Waveshare Spectra 6 SPI driver
│   ├── wifi_provision.h        ← captive portal provisioning
│   ├── bmp_render.h            ← image render helpers
│   └── mock-server.js          ← Node.js dev server (no Supabase needed)
├── memry-web/
│   ├── app/
│   │   ├── api/device/[id]/    ← firmware polls this
│   │   ├── dashboard/          ← upload, library, devices, settings
│   │   └── auth/               ← sign in / sign up
│   ├── lib/
│   │   ├── imageProcess.ts     ← Sharp + Floyd-Steinberg + 4bpp
│   │   └── supabase-*.ts       ← Supabase clients
│   ├── supabase-schema.sql     ← run once in Supabase SQL editor
│   ├── .env.local.example      ← copy to .env.local and fill in
│   └── SETUP.md                ← web-portal-specific notes
└── memry-shell/
    ├── memry_front_panel.stl   ← 3D print: 4× white PLA 0.15mm
    ├── memry_back_panel.stl    ← 3D print: 4× white PLA 0.15mm
    └── memry_shell_v4.scad     ← source file (OpenSCAD)
```

---

*MEMRY · v1.0 · Pune · 2025 · 87 days to July 11*

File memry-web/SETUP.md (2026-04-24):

# MEMRY — Setup Guide

Complete instructions from zero to a running portal with devices polling it.

---

## 1. Supabase project

1. Go to [app.supabase.com](https://app.supabase.com) → **New project**
2. Name it `memry`, pick a region close to Pune (Mumbai / Singapore)
3. Wait for provisioning (~2 min)

### Run the schema

**SQL Editor → New query** → paste the entire contents of `supabase-schema.sql` → **Run**

You should see: "Success. No rows returned."

### Create the storage bucket

**Storage → New bucket**

| Field | Value |
|---|---|
| Name | `photos` |
| Public | ❌ (private) |
| File size limit | 10 MB |
| Allowed MIME types | `application/octet-stream, image/jpeg, image/png, image/webp, image/heic` |

### Enable Google OAuth (optional)

**Authentication → Providers → Google**

- Toggle enabled
- Add your Google OAuth Client ID + Secret
- Authorised redirect URI: `https://your-project-ref.supabase.co/auth/v1/callback`

### Copy credentials

**Settings → API**

Copy these three values into `.env.local`:
- Project URL → `NEXT_PUBLIC_SUPABASE_URL`
- `anon` public key → `NEXT_PUBLIC_SUPABASE_ANON_KEY`
- `service_role` key → `SUPABASE_SERVICE_ROLE_KEY`

---

## 2. Local development

```bash
# Install dependencies
npm install

# Copy and fill env vars
cp .env.local.example .env.local
# Edit .env.local with your Supabase credentials

# Start dev server
npm run dev
# → http://localhost:3000
```

**In Supabase Authentication → URL Configuration:**
- Site URL: `http://localhost:3000`
- Redirect URLs: `http://localhost:3000/auth/callback`

---

## 3. Deploy to Vercel

```bash
# Install Vercel CLI (once)
npm i -g vercel

# Deploy
vercel --prod
```

When prompted, add environment variables from `.env.local`.

Or add them in the Vercel dashboard: **Project → Settings → Environment Variables**

**After deploying, update Supabase:**

Authentication → URL Configuration:
- Site URL: `https://your-app.vercel.app`
- Add redirect URL: `https://your-app.vercel.app/auth/callback`

---

## 4. Connect firmware

In `firmware/config.h`, update:

```cpp
#define SERVER_URL "https://your-app.vercel.app"
```

The device polls:
```
GET https://your-app.vercel.app/api/device/memry-001/current-image
```

Headers sent by firmware:
```
If-None-Match:  "memry-{photo_uuid}"   ← ETag from last fetch
X-Battery-Mv:   3850                    ← ADC battery reading
```

Responses:
```
200  Raw 4bpp binary (120 000 bytes)
     ETag: "memry-{photo_uuid}"
     X-Sleep-Hours: 4

304  Not modified — device skips render, goes back to sleep
     ETag: "memry-{photo_uuid}"
     X-Sleep-Hours: 4

404  No active photo — device sleeps and retries next cycle
```

---

## 5. First-run flow

1. Sign up at `https://your-app.vercel.app/auth`
2. Dashboard → **Pair device** → enter the 3-digit ID from your device sticker
3. Dashboard → **Upload photo** → drop a photo → select device → **Send to fridge**
4. Device wakes on its next cycle, fetches the image, renders it (19s for Spectra 6), sleeps

---

## 6. Image pipeline

What happens when you upload a photo:

```
Your photo (any format/size)
  │
  ▼ Sharp.js resize
  600 × 400 px (cover, centre crop)
  │
  ▼ Floyd-Steinberg dithering
  Quantised to Spectra 6 palette:
    0x0  Black   #1A140E
    0x1  White   #F5F0E8
    0x2  Green   #3D6B43
    0x3  Blue    #1E3A5A
    0x4  Red     #B84A2A
    0x5  Yellow  #C9A96E
  │
  ▼ Pack as 4bpp
  2 pixels per byte → 120 000 bytes total
  │
  ├→ Supabase Storage: processed/{device_id}/{photo_id}.bin  ← firmware fetches this
  └→ Supabase Storage: previews/{device_id}/{photo_id}.jpg   ← dashboard thumbnails
```

The upload page shows a **live client-side preview** of this process using the same
Floyd-Steinberg algorithm running in the browser — what you see is exactly what the
display will render.

---

## 7. Database schema

```
devices         id, name, owner_id, sleep_hours, display_type
photos          id, device_id, uploaded_by, storage_path, preview_path, caption, is_active
device_pings    device_id, last_request, battery_mv
device_settings device_id, rotation_mode, rotation_hours, show_caption
contributors    device_id, user_id, invited_by
```

All tables have Row Level Security enabled. The device API uses the
`service_role` key (bypasses RLS) to serve images without user auth.

---

## 8. Project structure

```
memry-web/
├── app/
│   ├── page.tsx                      → / (landing or dashboard redirect)
│   ├── landing/page.tsx              → Landing page with 3D Polaroid
│   ├── auth/
│   │   ├── page.tsx                  → Sign in / sign up / forgot password
│   │   ├── callback/route.ts         → OAuth callback
│   │   └── signout/route.ts          → POST sign out
│   ├── dashboard/
│   │   ├── layout.tsx                → Auth guard + sidebar
│   │   ├── page.tsx                  → Overview — device cards + stats
│   │   ├── upload/page.tsx           → Upload + live e-ink preview
│   │   ├── library/page.tsx          → Photo grid — filter, activate, delete
│   │   ├── contributors/page.tsx     → Manage contributors across devices
│   │   ├── settings/page.tsx         → Account settings
│   │   └── devices/
│   │       ├── page.tsx              → Device list
│   │       ├── pair/page.tsx         → 3-step pairing flow
│   │       └── [id]/page.tsx         → Device settings + contributors
│   └── api/
│       ├── device/[id]/route.ts      ← FIRMWARE POLLS THIS
│       ├── devices/route.ts          → GET all devices
│       ├── devices/[id]/route.ts     → PATCH name/settings, DELETE
│       ├── photos/upload/route.ts    → POST upload + process
│       ├── photos/[id]/route.ts      → DELETE photo + storage
│       ├── photos/[id]/activate/     → PATCH set active
│       ├── preview/[...path]/        → Signed URL proxy
│       └── activity/route.ts         → GET recent events
├── components/
│   ├── layout/Sidebar.tsx
│   ├── layout/Topbar.tsx
│   └── polaroid/Polaroid.tsx
├── lib/
│   ├── supabase-browser.ts           → Browser Supabase client
│   ├── supabase-server.ts            → Server + admin Supabase clients
│   └── imageProcess.ts              → Sharp + Floyd-Steinberg + 4bpp
├── types/index.ts                    → All TypeScript types
├── middleware.ts                     → Auth redirect guard
├── supabase-schema.sql               → Run once in Supabase SQL Editor
└── SETUP.md                          → This file
```

---

## 9. What's not yet built

These are the next things to add when the hardware ships:

- **Contributor invite by email** — needs a Supabase Edge Function to look up
  users by email server-side (the `auth.users` table is not accessible from
  client-side RLS). See `supabase/functions/invite/index.ts` for a template.

- **Auto-rotation** — when `device_settings.rotation_mode = 'auto'`, a
  scheduled job (Supabase pg_cron or Vercel Cron) should rotate the active
  photo on the configured interval.

- **Push on upload** — instead of waiting for the next deep-sleep wake, a
  WebSocket or Server-Sent Events endpoint could tell the device to wake early.
  Requires firmware changes to keep WiFi active briefly after render.

- **Activity feed on dashboard** — wire the `/api/activity` route into the
  dashboard page's activity section (data fetching is done, UI exists).

---

*MEMRY · v1.0 · Built in Pune · July 2025*

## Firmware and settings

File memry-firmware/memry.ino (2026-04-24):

// ─────────────────────────────────────────────────────────────
//  MEMRY — memry.ino
//  Waveshare 3.6" e-Paper HAT+ (E) · SKU 32650 · Spectra 6
//  Seeed XIAO ESP32C3
//
//  Lifecycle (every wake):
//    Boot → load WiFi creds → if none: provisioning portal
//    → connect WiFi → GET /api/device/{id}/current-image
//    → ETag check → render if new → EPD sleep → deep sleep
//
//  Libraries (Arduino Library Manager):
//    · ArduinoJson  by Benoit Blanchon (v6.x)
//    · WiFi / HTTPClient / WebServer / DNSServer / Preferences
//      → all built-in to Seeed XIAO ESP32C3 board package
//
//  NO GxEPD2 needed — we use our own driver (epd3in6e_driver.h)
// ─────────────────────────────────────────────────────────────

#include "config.h"
#include "epd3in6e_driver.h"
#include "wifi_provision.h"

#include <WiFi.h>
#include <HTTPClient.h>
#include <Preferences.h>

// ── RTC memory — survives deep sleep, cleared on power-cycle ──
RTC_DATA_ATTR char lastEtag[64]         = "";
RTC_DATA_ATTR int  wakeCount            = 0;
RTC_DATA_ATTR bool firstBoot            = true;
RTC_DATA_ATTR int  consecutiveWifiFail  = 0;

// ── Forward declarations ───────────────────────────────────────
bool connectWiFi(const char* ssid, const char* pass);
int  fetchImage(const String& url, const String& etag,
                String& newEtag, uint8_t** outBuf, size_t& outLen,
                int& sleepHours);
void showProvisioningScreen();
void showStatus(const char* line1, const char* line2 = nullptr);
void drawTextOnEPD(const char* msg, int x, int y);
void goSleep(int hours);
uint32_t readBatteryMv();

// ──────────────────────────────────────────────────────────────
void setup() {
  Serial.begin(115200);
  delay(200);
  wakeCount++;
  Serial.printf("\n── MEMRY wake #%d  device=%s ──\n", wakeCount, DEVICE_ID);

  // ── Init display ─────────────────────────────────────────────
  epdInit();

  // ── Load WiFi credentials ─────────────────────────────────────
  String ssid, pass;
  bool hasCreds = provLoadCreds(ssid, pass);

  if (!hasCreds) {
    Serial.println("No WiFi creds — starting provisioning portal");
    showProvisioningScreen();
    bool saved = runProvisioningPortal();
    epdSleep();
    if (saved) {
      ESP.restart();
    } else {
      goSleep(SLEEP_HOURS_ON_ERROR);
    }
    return;
  }

  // ── Connect WiFi ──────────────────────────────────────────────
  if (!connectWiFi(ssid.c_str(), pass.c_str())) {
    consecutiveWifiFail++;
    Serial.printf("WiFi failed (%d consecutive)\n", consecutiveWifiFail);

    if (consecutiveWifiFail >= WIFI_FAILS_BEFORE_REPROVISION) {
      consecutiveWifiFail = 0;
      memset(lastEtag, 0, sizeof(lastEtag));
      provClearCreds();
      showStatus("WiFi lost.", "Connect to MEMRY-Setup.");
    } else {
      showStatus("No WiFi.", "Retrying next cycle.");
    }
    epdSleep();
    goSleep(SLEEP_HOURS_ON_ERROR);
    return;
  }

  consecutiveWifiFail = 0;

  // ── Read battery ──────────────────────────────────────────────
  uint32_t battMv = readBatteryMv();
  Serial.printf("Battery: %umV\n", battMv);

  // ── Fetch image ───────────────────────────────────────────────
  String url = String(SERVER_URL) + "/api/device/" + DEVICE_ID + "/current-image";
  Serial.printf("Fetching %s\n", url.c_str());

  String   newEtag    = "";
  uint8_t* imgBuf     = nullptr;
  size_t   imgLen     = 0;
  int      sleepHours = SLEEP_HOURS_DEFAULT;

  int code = fetchImage(url, String(lastEtag), newEtag, &imgBuf, imgLen, sleepHours);

  WiFi.disconnect(true);
  WiFi.mode(WIFI_OFF);

  if (code == 200 && imgBuf && imgLen > 0) {
    Serial.printf("New image — %u bytes, ETag: %s\n", imgLen, newEtag.c_str());

    // Render — use rotated if display is portrait-mounted
    // Change to epdRender() if landscape orientation preferred
    epdRenderRotated(imgBuf, imgLen);

    strncpy(lastEtag, newEtag.c_str(), sizeof(lastEtag) - 1);
    free(imgBuf);

  } else if (code == 304) {
    Serial.println("304 — image unchanged, skipping render");

  } else {
    Serial.printf("HTTP error %d\n", code);
  }

  epdSleep();
  goSleep(sleepHours);
}

void loop() {}

// ──────────────────────────────────────────────────────────────
bool connectWiFi(const char* ssid, const char* pass) {
  WiFi.mode(WIFI_STA);
  WiFi.begin(ssid, pass);

  for (int attempt = 0; attempt < WIFI_RETRIES; attempt++) {
    uint32_t t0 = millis();
    while (millis() - t0 < WIFI_TIMEOUT_MS) {
      if (WiFi.status() == WL_CONNECTED) {
        Serial.printf("WiFi connected: %s (attempt %d)\n",
                      WiFi.localIP().toString().c_str(), attempt + 1);
        return true;
      }
      delay(200);
    }
    Serial.printf("Attempt %d timed out\n", attempt + 1);
    WiFi.disconnect();
    delay(500);
    WiFi.begin(ssid, pass);
  }
  return false;
}

// ──────────────────────────────────────────────────────────────
int fetchImage(const String& url, const String& etag,
               String& newEtag, uint8_t** outBuf, size_t& outLen,
               int& sleepHours) {

  HTTPClient http;
  http.begin(url);
  http.setTimeout(HTTP_TIMEOUT_MS);
  http.addHeader("X-Device-ID", DEVICE_ID);
  http.addHeader("X-Battery-Mv", String(readBatteryMv()));
  if (etag.length() > 0) http.addHeader("If-None-Match", etag);

  int code = http.GET();
  Serial.printf("HTTP %d\n", code);

  if (code == 304) { http.end(); return 304; }
  if (code != 200) { http.end(); return code; }

  String sh = http.header("X-Sleep-Hours");
  if (sh.length() > 0) {
    int h = sh.toInt();
    if (h >= 1 && h <= 24) sleepHours = h;
  }
  newEtag = http.header("ETag");

  int contentLen = http.getSize();
  Serial.printf("Content-Length: %d\n", contentLen);

  if (contentLen <= 0 || contentLen > MAX_IMAGE_BYTES) {
    Serial.printf("Bad content-length: %d\n", contentLen);
    http.end(); return -1;
  }

  *outBuf = (uint8_t*)malloc(contentLen);
  if (!*outBuf) { Serial.println("malloc failed"); http.end(); return -1; }

  WiFiClient* stream = http.getStreamPtr();
  size_t received = 0;
  uint32_t t0 = millis();
  while (received < (size_t)contentLen && millis() - t0 < HTTP_TIMEOUT_MS) {
    if (stream->available()) {
      received += stream->readBytes(*outBuf + received, contentLen - received);
    } else {
      delay(5);
    }
  }
  http.end();

  if (received != (size_t)contentLen) {
    Serial.printf("Incomplete: %u/%d bytes\n", received, contentLen);
    free(*outBuf); *outBuf = nullptr; return -1;
  }

  outLen = received;
  return 200;
}

// ──────────────────────────────────────────────────────────────
//  Battery voltage via ADC
//  XIAO ESP32C3: A0 (GPIO0) reads BAT pin through internal
//  voltage divider (1:2 ratio on XIAO C3).
//  Raw ADC at 12-bit: 0–4095 maps to 0–3.3V at pin.
//  Multiply by 2 to undo divider → actual battery voltage.
// ──────────────────────────────────────────────────────────────
uint32_t readBatteryMv() {
  // Stabilise ADC
  analogSetAttenuation(ADC_11db);  // 0–3.3V range
  delay(10);

  uint32_t raw = 0;
  for (int i = 0; i < 8; i++) raw += analogReadMilliVolts(A0);
  raw /= 8;

  // ×2 for the voltage divider
  return raw * 2;
}

// ──────────────────────────────────────────────────────────────
//  Status screens — draw text directly via SPI commands
//  (No GxEPD2, so we use simple raw pixel routines)
//
//  For these text screens we fill the display white and draw
//  a minimal message. Using a simple 5×7 bitmap font.
// ──────────────────────────────────────────────────────────────

// Minimal 5×7 font — just the characters we need for status
// Index: ASCII - 32 (space=0). Only common chars included.
static const uint8_t FONT5X7[][5] = {
  {0x00,0x00,0x00,0x00,0x00}, // ' '
  {0x00,0x00,0x5F,0x00,0x00}, // '!'
  {0x00,0x07,0x00,0x07,0x00}, // '"'
  {0x14,0x7F,0x14,0x7F,0x14}, // '#'
  {0x24,0x2A,0x7F,0x2A,0x12}, // '$'
  {0x23,0x13,0x08,0x64,0x62}, // '%'
  {0x36,0x49,0x55,0x22,0x50}, // '&'
  {0x00,0x05,0x03,0x00,0x00}, // '''
  {0x00,0x1C,0x22,0x41,0x00}, // '('
  {0x00,0x41,0x22,0x1C,0x00}, // ')'
  {0x14,0x08,0x3E,0x08,0x14}, // '*'
  {0x08,0x08,0x3E,0x08,0x08}, // '+'
  {0x00,0x50,0x30,0x00,0x00}, // ','
  {0x08,0x08,0x08,0x08,0x08}, // '-'
  {0x00,0x60,0x60,0x00,0x00}, // '.'
  {0x20,0x10,0x08,0x04,0x02}, // '/'
  {0x3E,0x51,0x49,0x45,0x3E}, // '0'
  {0x00,0x42,0x7F,0x40,0x00}, // '1'
  {0x42,0x61,0x51,0x49,0x46}, // '2'
  {0x21,0x41,0x45,0x4B,0x31}, // '3'
  {0x18,0x14,0x12,0x7F,0x10}, // '4'
  {0x27,0x45,0x45,0x45,0x39}, // '5'
  {0x3C,0x4A,0x49,0x49,0x30}, // '6'
  {0x01,0x71,0x09,0x05,0x03}, // '7'
  {0x36,0x49,0x49,0x49,0x36}, // '8'
  {0x06,0x49,0x49,0x29,0x1E}, // '9'
  {0x00,0x36,0x36,0x00,0x00}, // ':'
  {0x00,0x56,0x36,0x00,0x00}, // ';'
  {0x08,0x14,0x22,0x41,0x00}, // '<'
  {0x14,0x14,0x14,0x14,0x14}, // '='
  {0x00,0x41,0x22,0x14,0x08}, // '>'
  {0x02,0x01,0x51,0x09,0x06}, // '?'
  {0x32,0x49,0x79,0x41,0x3E}, // '@'
  {0x7E,0x11,0x11,0x11,0x7E}, // 'A'
  {0x7F,0x49,0x49,0x49,0x36}, // 'B'
  {0x3E,0x41,0x41,0x41,0x22}, // 'C'
  {0x7F,0x41,0x41,0x22,0x1C}, // 'D'
  {0x7F,0x49,0x49,0x49,0x41}, // 'E'
  {0x7F,0x09,0x09,0x09,0x01}, // 'F'
  {0x3E,0x41,0x49,0x49,0x7A}, // 'G'
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
};

// Draw a status screen (white bg, black text, 2 lines)
// Uses raw EPD pixel rendering via a framebuffer
void showStatus(const char* line1, const char* line2) {
  const int W = EPD_WIDTH;   // 600
  const int H = EPD_HEIGHT;  // 400
  const size_t bufSize = (W * H) / 2;

  uint8_t* fb = (uint8_t*)malloc(bufSize);
  if (!fb) {
    Serial.println("showStatus: malloc failed");
    return;
  }

  // Fill white (0x1 = white, packed: 0x11 per byte)
  memset(fb, 0x11, bufSize);

  // Helper: set a single pixel color in framebuffer
  auto setPixel = [&](int x, int y, uint8_t color) {
    if (x < 0 || x >= W || y < 0 || y >= H) return;
    int idx = y * W + x;
    if (idx % 2 == 0) fb[idx/2] = (fb[idx/2] & 0x0F) | ((color & 0xF) << 4);
    else              fb[idx/2] = (fb[idx/2] & 0xF0) |  (color & 0xF);
  };

  // Draw text at scale 2 (10×14 per char) using 5×7 font
  auto drawChar = [&](char c, int cx, int cy, int scale) {
    if (c < ' ' || c > 'Z') return;
    const uint8_t* glyph = FONT5X7[c - ' '];
    for (int col = 0; col < 5; col++) {
      for (int row = 0; row < 7; row++) {
        if (glyph[col] & (1 << row)) {
          for (int sy = 0; sy < scale; sy++)
            for (int sx = 0; sx < scale; sx++)
              setPixel(cx + col*scale + sx, cy + row*scale + sy, EPD_BLACK);
        }
      }
    }
  };

  auto drawString = [&](const char* s, int x, int y, int scale) {
    // Convert to uppercase for font coverage
    char upper[64];
    strncpy(upper, s, 63); upper[63]=0;
    for (int i = 0; upper[i]; i++) {
      if (upper[i] >= 'a' && upper[i] <= 'z') upper[i] -= 32;
    }
    int cx = x;
    for (int i = 0; upper[i]; i++) {
      drawChar(upper[i], cx, y, scale);
      cx += (5 + 1) * scale;
    }
  };

  // Draw content
  drawString("memry", 40, 140, 3);
  if (line1) drawString(line1, 40, 200, 2);
  if (line2) drawString(line2, 40, 230, 1);
  drawString(DEVICE_ID, 40, 340, 1);

  // Send to display
  epdRenderRotated(fb, bufSize);
  free(fb);
}

void showProvisioningScreen() {
  const int W = EPD_WIDTH;
  const int H = EPD_HEIGHT;
  const size_t bufSize = (W * H) / 2;

  uint8_t* fb = (uint8_t*)malloc(bufSize);
  if (!fb) return;
  memset(fb, 0x11, bufSize);  // White

  auto setPixel = [&](int x, int y, uint8_t color) {
    if (x < 0 || x >= W || y < 0 || y >= H) return;
    int idx = y * W + x;
    if (idx % 2 == 0) fb[idx/2] = (fb[idx/2] & 0x0F) | ((color & 0xF) << 4);
    else              fb[idx/2] = (fb[idx/2] & 0xF0) |  (color & 0xF);
  };

  auto drawChar = [&](char c, int cx, int cy, int scale) {
    if (c < ' ' || c > 'Z') return;
    const uint8_t* glyph = FONT5X7[c - ' '];
    for (int col = 0; col < 5; col++)
      for (int row = 0; row < 7; row++)
        if (glyph[col] & (1 << row))
          for (int sy = 0; sy < scale; sy++)
            for (int sx = 0; sx < scale; sx++)
              setPixel(cx + col*scale + sx, cy + row*scale + sy, EPD_BLACK);
  };

  auto drawString = [&](const char* s, int x, int y, int scale) {
    char upper[64]; strncpy(upper, s, 63); upper[63]=0;
    for (int i = 0; upper[i]; i++)
      if (upper[i] >= 'a' && upper[i] <= 'z') upper[i] -= 32;
    int cx = x;
    for (int i = 0; upper[i]; i++) { drawChar(upper[i], cx, y, scale); cx += (5+1)*scale; }
  };

  auto fillRect = [&](int x, int y, int w, int h, uint8_t color) {
    for (int ry = y; ry < y+h; ry++)
      for (int rx = x; rx < x+w; rx++)
        setPixel(rx, ry, color);
  };

  drawString("setup", 40, 60, 3);
  fillRect(40, 100, 520, 2, EPD_BLACK);  // divider

  drawString("1. open wifi settings", 40, 120, 1);
  drawString("2. connect to:", 40, 140, 1);

  // Highlight box for network name
  fillRect(36, 158, 300, 26, EPD_BLACK);
  drawString("memry-setup", 42, 163, 2);

  // White text inside black box — redraw with white
  auto drawStringColor = [&](const char* s, int x, int y, int scale, uint8_t color) {
    char upper[64]; strncpy(upper, s, 63); upper[63]=0;
    for (int i = 0; upper[i]; i++) if (upper[i]>='a'&&upper[i]<='z') upper[i]-=32;
    int cx = x;
    for (int i = 0; upper[i]; i++) {
      if (upper[i] < ' ' || upper[i] > 'Z') { cx += (5+1)*scale; continue; }
      const uint8_t* glyph = FONT5X7[upper[i]-' '];
      for (int col = 0; col < 5; col++)
        for (int row = 0; row < 7; row++)
          if (glyph[col] & (1 << row))
            for (int sy = 0; sy < scale; sy++)
              for (int sx = 0; sx < scale; sx++)
                setPixel(cx+col*scale+sx, y+row*scale+sy, color);
      cx += (5+1)*scale;
    }
  };
  drawStringColor("memry-setup", 42, 163, 2, EPD_WHITE);

  drawString("3. setup page will open", 40, 200, 1);
  drawString("4. enter your wifi password", 40, 218, 1);

  drawString(DEVICE_ID, 40, 340, 1);
  drawString("memry", 40, 358, 1);

  epdRenderRotated(fb, bufSize);
  free(fb);
}

// ──────────────────────────────────────────────────────────────
void goSleep(int hours) {
  Serial.printf("Sleeping %dh...\n\n", hours);
  Serial.flush();
  esp_sleep_enable_timer_wakeup((uint64_t)hours * 3600ULL * 1000000ULL);
  esp_deep_sleep_start();
}

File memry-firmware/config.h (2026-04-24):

// ─────────────────────────────────────────────────────────────
//  MEMRY — config.h
//  Display: Waveshare 3.6" e-Paper HAT+ (E), SKU 32650
//           Spectra 6, 600×400, 6-color, 4bpp
//  Board:   Seeed XIAO ESP32C3
//
//  Only change DEVICE_ID per unit. WiFi creds entered via
//  provisioning portal on first boot — not stored here.
// ─────────────────────────────────────────────────────────────
#pragma once

// ── Device identity (change per unit: 001, 002, 003, 004) ────
#define DEVICE_ID     "memry-001"

// ── Server ────────────────────────────────────────────────────
// Dev:  your laptop LAN IP e.g. "http://192.168.1.42:3001"
// Prod: "https://api.memry.app"
#define SERVER_URL    "http://192.168.1.42:3001"

// ── WiFi ──────────────────────────────────────────────────────
#define WIFI_RETRIES                  3
#define WIFI_TIMEOUT_MS               20000
#define WIFI_FAILS_BEFORE_REPROVISION 5

// ── Sleep ─────────────────────────────────────────────────────
#define SLEEP_HOURS_DEFAULT           4
#define SLEEP_HOURS_ON_ERROR          1

// ── HTTP ──────────────────────────────────────────────────────
#define HTTP_TIMEOUT_MS               30000
// 600×400 @ 4bpp = 120,000 bytes. Add headroom for any framing.
#define MAX_IMAGE_BYTES               131072   // 128KB cap

// ── Pin mapping — XIAO ESP32C3 → Waveshare HAT+ breakout ─────
//
//  Use the 9-pin breakout connector on the RIGHT side of the
//  HAT+ PCB (NOT the 40-pin Pi header).
//
//  HAT+ breakout   XIAO ESP32C3
//  ─────────────────────────────────────────
//  GND          →  GND
//  VCC          →  3.3V
//  DIN (MOSI)   →  D10  (GPIO3)
//  CLK (SCK)    →  D8   (GPIO2)
//  CS           →  D7   (GPIO20)
//  DC           →  D3   (GPIO21)
//  RST          →  D0   (GPIO9)
//  BUSY         ←  D1   (GPIO10)
//  PWR          →  3.3V  (must be HIGH or display won't power on)
//
//  ⚠️  PWR pin: tie to 3.3V. Without it the display stays dark.
//  ⚠️  Interface switch on HAT+ PCB: leave at 0 (4-line SPI).
//
#define PIN_DIN   D10   // GPIO3  — SPI MOSI
#define PIN_CLK   D8    // GPIO2  — SPI SCK
#define PIN_CS    D7    // GPIO20
#define PIN_DC    D3    // GPIO21
#define PIN_RST   D0    // GPIO9
#define PIN_BUSY  D1    // GPIO10
// PWR: wire directly to 3.3V on breadboard — no GPIO needed

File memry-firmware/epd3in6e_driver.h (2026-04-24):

// ─────────────────────────────────────────────────────────────
//  MEMRY — epd3in6e_driver.h
//  Driver for Waveshare 3.6" e-Paper HAT+ (E), SKU 32650
//  E Ink Spectra 6, 600×400, 6-color
//
//  Image format from server (4bpp packed):
//    · 2 pixels per byte
//    · High nibble = left pixel, low nibble = right pixel
//    · Color index: Black=0, White=1, Green=2, Blue=3, Red=4, Yellow=5
//    · Total bytes for 600×400: 600*400/2 = 120,000 bytes
//
//  This file contains:
//    · Low-level SPI send functions
//    · Display init, clear, sleep sequences
//    · Image render (streams 4bpp buffer to display)
//
//  Based on Waveshare's official epd3in6e Arduino demo,
//  adapted for XIAO ESP32C3 pin mapping and our image format.
// ─────────────────────────────────────────────────────────────
#pragma once

#include <SPI.h>
#include <Arduino.h>
#include "config.h"

// ── Display constants ─────────────────────────────────────────
#define EPD_WIDTH   600
#define EPD_HEIGHT  400

// Color indices (match server-side image pipeline)
#define EPD_BLACK   0x0
#define EPD_WHITE   0x1
#define EPD_GREEN   0x2
#define EPD_BLUE    0x3
#define EPD_RED     0x4
#define EPD_YELLOW  0x5

// ── SPI primitives ────────────────────────────────────────────

static void _epdSendCommand(uint8_t cmd) {
  digitalWrite(PIN_DC, LOW);
  digitalWrite(PIN_CS, LOW);
  SPI.transfer(cmd);
  digitalWrite(PIN_CS, HIGH);
}

static void _epdSendData(uint8_t data) {
  digitalWrite(PIN_DC, HIGH);
  digitalWrite(PIN_CS, LOW);
  SPI.transfer(data);
  digitalWrite(PIN_CS, HIGH);
}

static void _epdSendDataBuf(const uint8_t* buf, size_t len) {
  digitalWrite(PIN_DC, HIGH);
  digitalWrite(PIN_CS, LOW);
  SPI.transferBytes(buf, nullptr, len);
  digitalWrite(PIN_CS, HIGH);
}

static void _epdWaitBusy() {
  // BUSY is HIGH while the display is processing
  // Poll until it goes LOW (idle)
  uint32_t t0 = millis();
  while (digitalRead(PIN_BUSY) == HIGH) {
    if (millis() - t0 > 30000) {
      Serial.println("EPD BUSY timeout!");
      break;
    }
    delay(10);
  }
}

static void _epdReset() {
  digitalWrite(PIN_RST, HIGH);
  delay(20);
  digitalWrite(PIN_RST, LOW);
  delay(2);
  digitalWrite(PIN_RST, HIGH);
  delay(20);
  _epdWaitBusy();
}

// ── Public API ────────────────────────────────────────────────

void epdInit() {
  // Setup pins
  pinMode(PIN_CS,   OUTPUT);
  pinMode(PIN_DC,   OUTPUT);
  pinMode(PIN_RST,  OUTPUT);
  pinMode(PIN_BUSY, INPUT);
  digitalWrite(PIN_CS, HIGH);

  // Init SPI — XIAO ESP32C3 hardware SPI
  SPI.begin(PIN_CLK, -1, PIN_DIN, PIN_CS);
  SPI.beginTransaction(SPISettings(4000000, MSBFIRST, SPI_MODE0));

  _epdReset();

  // Power on sequence (from Waveshare epd3in6e demo)
  _epdSendCommand(0x00);  // Panel setting
  _epdSendData(0xEF);
  _epdSendData(0x08);

  _epdSendCommand(0x01);  // Power setting
  _epdSendData(0x37);
  _epdSendData(0x00);
  _epdSendData(0x23);
  _epdSendData(0x23);

  _epdSendCommand(0x03);  // Power off sequence
  _epdSendData(0x00);

  _epdSendCommand(0x06);  // Booster soft start
  _epdSendData(0xC7);
  _epdSendData(0xC7);
  _epdSendData(0x1D);

  _epdSendCommand(0x30);  // PLL control
  _epdSendData(0x3C);

  _epdSendCommand(0x41);  // Temperature sensor selection (internal)
  _epdSendData(0x00);

  _epdSendCommand(0x50);  // VCOM and data interval setting
  _epdSendData(0x37);

  _epdSendCommand(0x60);  // TCON setting
  _epdSendData(0x22);

  _epdSendCommand(0x61);  // Resolution setting
  _epdSendData(EPD_WIDTH >> 8);
  _epdSendData(EPD_WIDTH & 0xFF);
  _epdSendData(EPD_HEIGHT >> 8);
  _epdSendData(EPD_HEIGHT & 0xFF);

  _epdSendCommand(0xE3);  // PWS setting
  _epdSendData(0xAA);

  delay(100);

  _epdSendCommand(0x50);
  _epdSendData(0x37);

  Serial.println("EPD init done");
}

// ── Clear display to white ────────────────────────────────────
void epdClear() {
  _epdSendCommand(0x61);  // Resolution
  _epdSendData(EPD_WIDTH >> 8);
  _epdSendData(EPD_WIDTH & 0xFF);
  _epdSendData(EPD_HEIGHT >> 8);
  _epdSendData(EPD_HEIGHT & 0xFF);

  _epdSendCommand(0x10);  // Start data transmission

  // White = 0x11 (two white pixels per byte)
  const size_t bytes = (EPD_WIDTH * EPD_HEIGHT) / 2;
  for (size_t i = 0; i < bytes; i++) {
    _epdSendData(0x11);
  }

  _epdSendCommand(0x04);  // Power on
  _epdWaitBusy();
  _epdSendCommand(0x12);  // Refresh
  _epdWaitBusy();
  _epdSendCommand(0x02);  // Power off
  _epdWaitBusy();

  Serial.println("EPD cleared");
}

// ── Render image from 4bpp packed buffer ─────────────────────
//
//  buf: server image buffer, 120,000 bytes for 600×400
//  len: must be exactly (EPD_WIDTH * EPD_HEIGHT) / 2
//
//  The display expects exactly the same 4bpp format we receive
//  from the server, so we stream it directly. No pixel-by-pixel
//  conversion needed.
//
//  Rotation: call epdRenderRotated() for portrait orientation.
//
void epdRender(const uint8_t* buf, size_t len) {
  const size_t expected = (EPD_WIDTH * EPD_HEIGHT) / 2;

  if (len != expected) {
    Serial.printf("EPD render: bad buffer size %u, expected %u\n", len, expected);
    return;
  }

  Serial.printf("EPD rendering %u bytes...\n", len);
  uint32_t t0 = millis();

  _epdSendCommand(0x61);  // Resolution
  _epdSendData(EPD_WIDTH >> 8);
  _epdSendData(EPD_WIDTH & 0xFF);
  _epdSendData(EPD_HEIGHT >> 8);
  _epdSendData(EPD_HEIGHT & 0xFF);

  _epdSendCommand(0x10);  // Data transmission start

  // Stream in chunks to avoid SPI buffer limits
  const size_t CHUNK = 4096;
  size_t sent = 0;
  while (sent < len) {
    size_t chunk = min(CHUNK, len - sent);
    _epdSendDataBuf(buf + sent, chunk);
    sent += chunk;
  }

  _epdSendCommand(0x04);  // Power on
  _epdWaitBusy();

  _epdSendCommand(0x12);  // Refresh — this takes ~19s for Spectra 6
  Serial.println("EPD refreshing (this takes ~19s)...");
  _epdWaitBusy();

  _epdSendCommand(0x02);  // Power off
  _epdWaitBusy();

  Serial.printf("EPD render done in %lums\n", millis() - t0);
}
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
